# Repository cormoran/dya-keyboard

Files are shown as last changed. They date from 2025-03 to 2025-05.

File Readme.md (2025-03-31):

#  DYA Split Keyboard

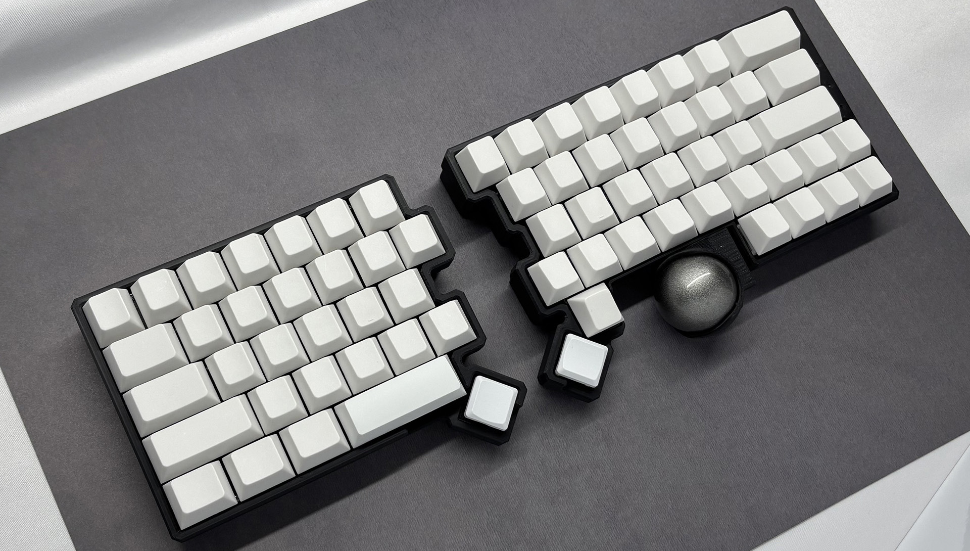
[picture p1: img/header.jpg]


## Features

- Controller: RP2040-zero (QMK) and XAIO NRF52840 plus (ZMK)
  - ZMK firmware is not available yet, since XAIO NRF52840 plus cannot be used in Japan for now.
- Layout: US and JIS
- Switch: Cherry MX compatible, hotswappable
- LED x 12 (left 4, right 4 + 4 indicator)
- PMW3610 low power trackball sensor
- Optional features by soldering additional parts
  - Lipo battery support for XAIO
  - AAA battery (1.2V NiMH or 1.5V) support

## Build Guide

[V1.0 部品取り付け済み基板（日本語）](./hardware/dya-v1/build-guide/pcba/Readme-ja.md)

## Firmware

Pre-built QMK firmware is available in latest build's artifact section in [this github actions](https://github.com/cormoran/dya-keyboard/actions/workflows/main.yml).

Three binaries (via, us, jis) are zipped in `dya_qmk_latest.zip`. `via` binary supports [VIA](https://www.usevia.app/) and [Remap](https://remap-keys.app/) to change keymapping. Keyboard definition json for VIA is available in [`./firmware/qmk/keybaords/dya/dya-via.json`](https://github.com/cormoran/dya-keyboard/blob/main/firmware/qmk/keyboards/dya/dya-via.json).

## Gallery

- Keycap: [acid-caps](https://keeb-on.com/collections/acid-caps) or no-brand white cap
- Trackball: 34mm

### US Layout setup

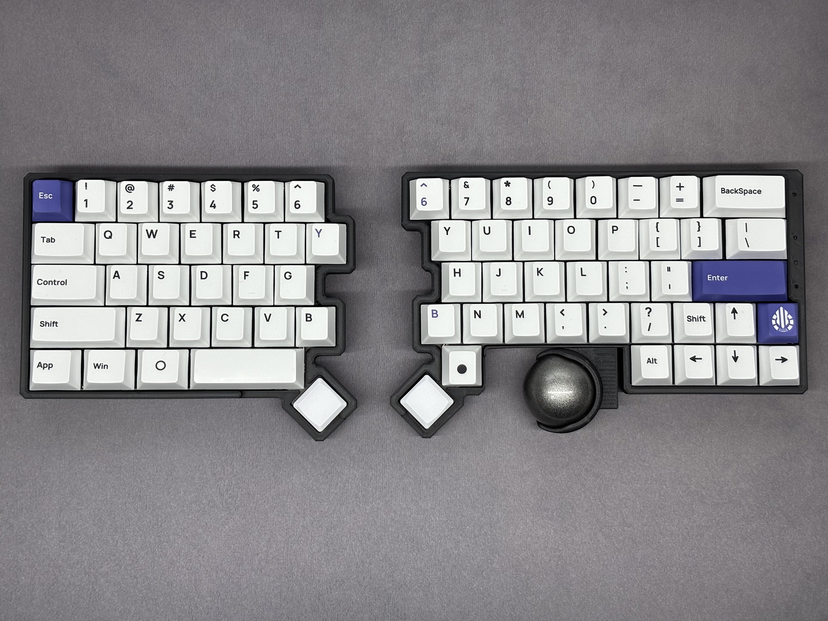
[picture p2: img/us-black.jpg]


#### LED decoration and indicators

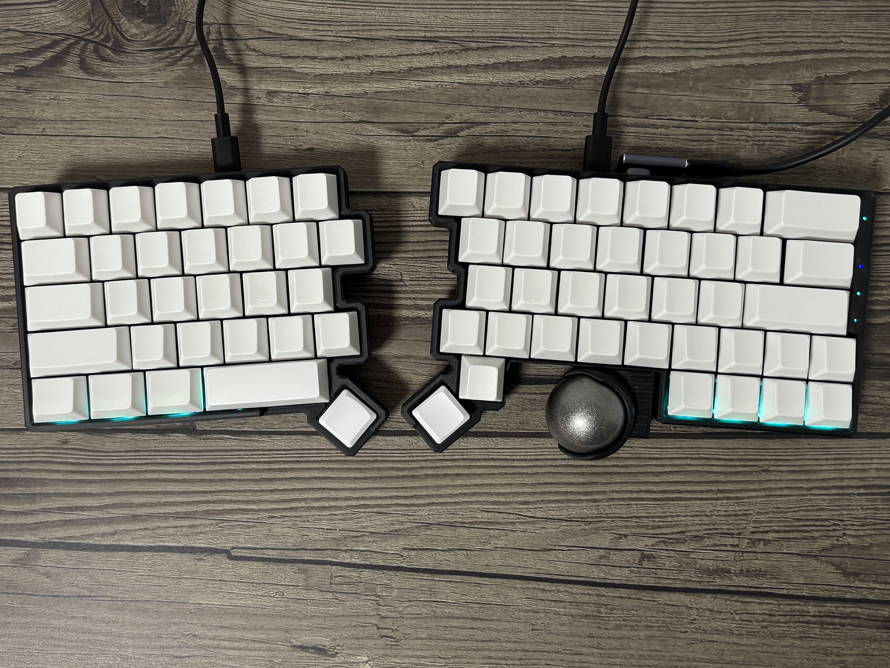
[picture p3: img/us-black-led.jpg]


### JIS Layout setup

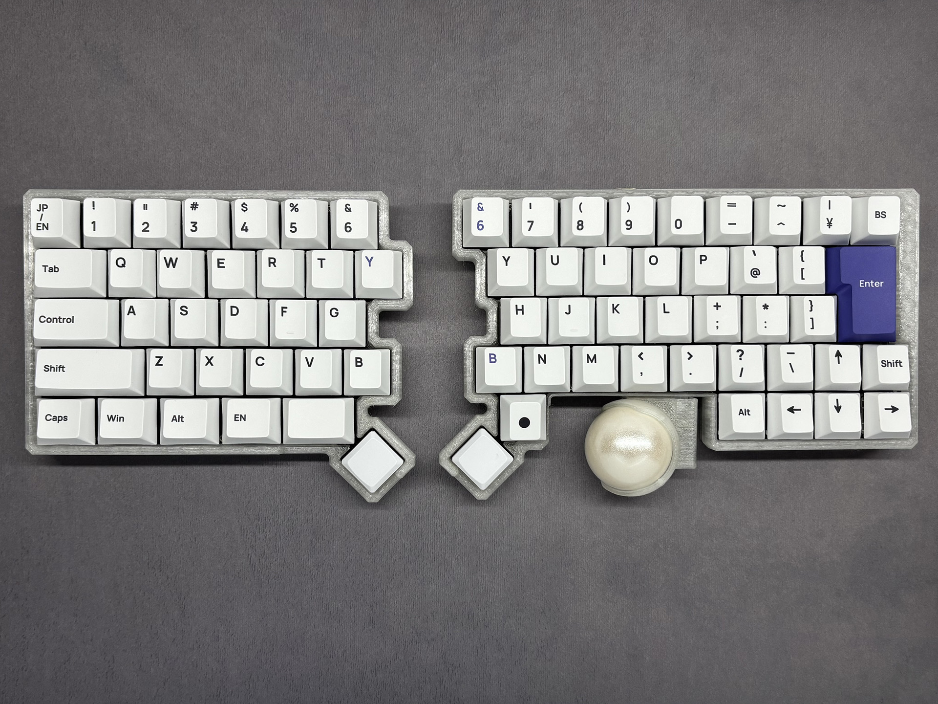
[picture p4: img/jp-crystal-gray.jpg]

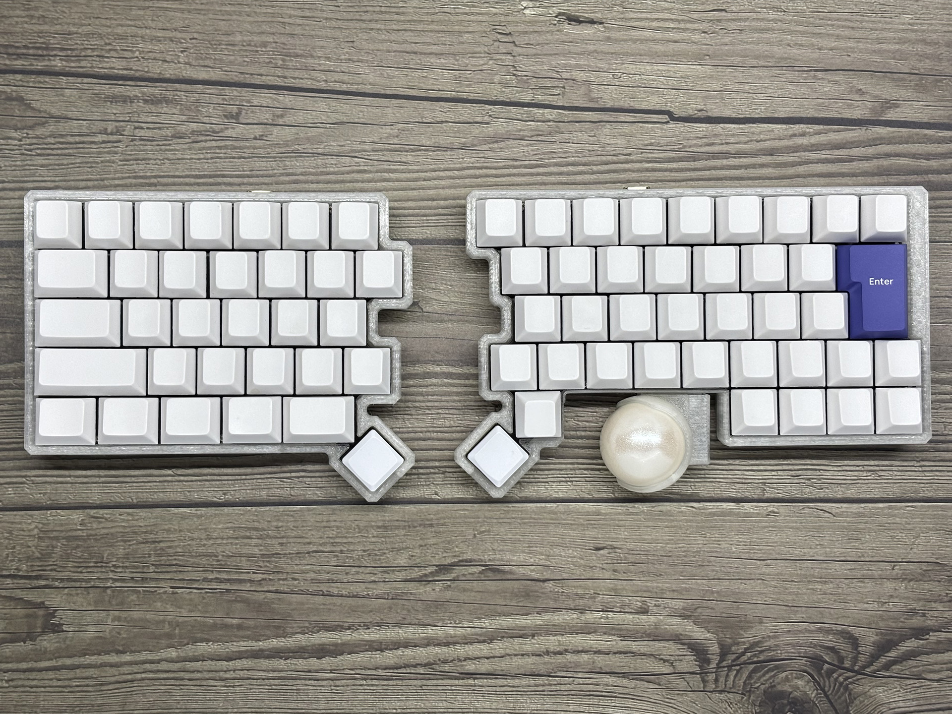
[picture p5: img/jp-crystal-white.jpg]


### Schematic

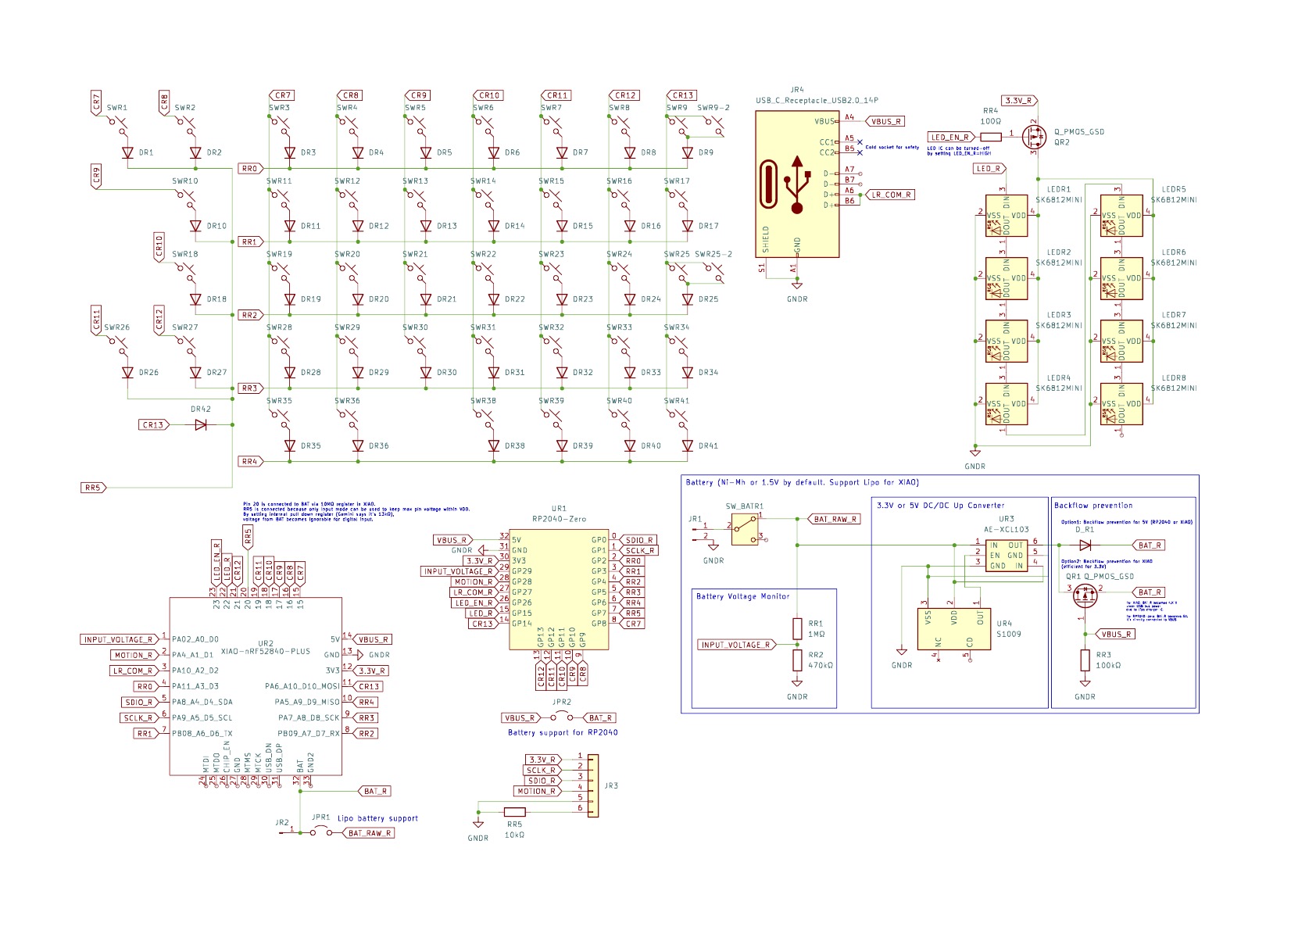
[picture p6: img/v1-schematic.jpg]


## Shop

Available in https://cormoran707.booth.pm/items/6705756

## License

- QMK firmware (./firmware/qmk_firmware/\*): Inherits its license. Majority of them are under GPLv2. See its own repository.
- DYA logo  (./img/dya.svg): All rights reserved.
- Other keyboard pictures under ./img: CC BY
- Hardware
  - kicad library (./hardware/kicad_library/\*) and sch (\*.kicad_sch): MIT
  - PCB (\*.kicad_pcb): CC BY-NC
  - Case data (\*.stl): CC BY

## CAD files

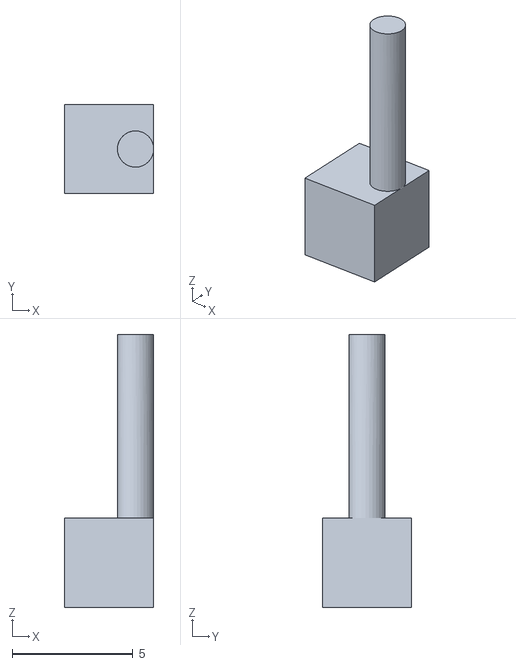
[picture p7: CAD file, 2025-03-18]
hardware/dya-v1/case/led.stl
3.70 x 3.70 x 11.3

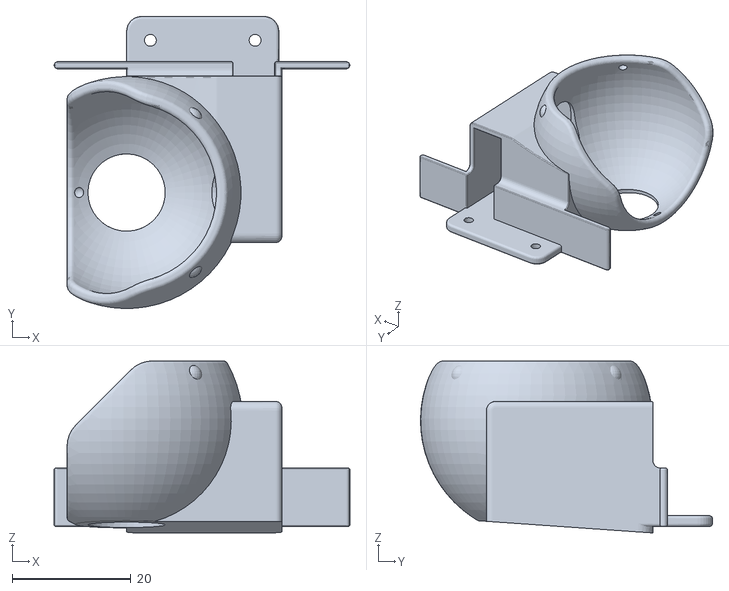
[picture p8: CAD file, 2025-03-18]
hardware/dya-v1/case/trackball-34mm.stl
49.7 x 49.1 x 28.9

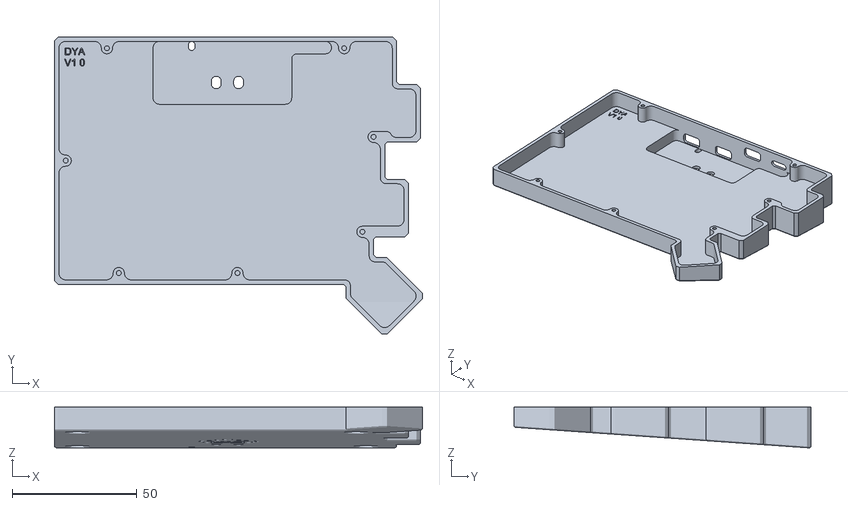
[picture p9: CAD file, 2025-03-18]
hardware/dya-v1/case/bottom-left.stl
147.7 x 119.2 x 16.4

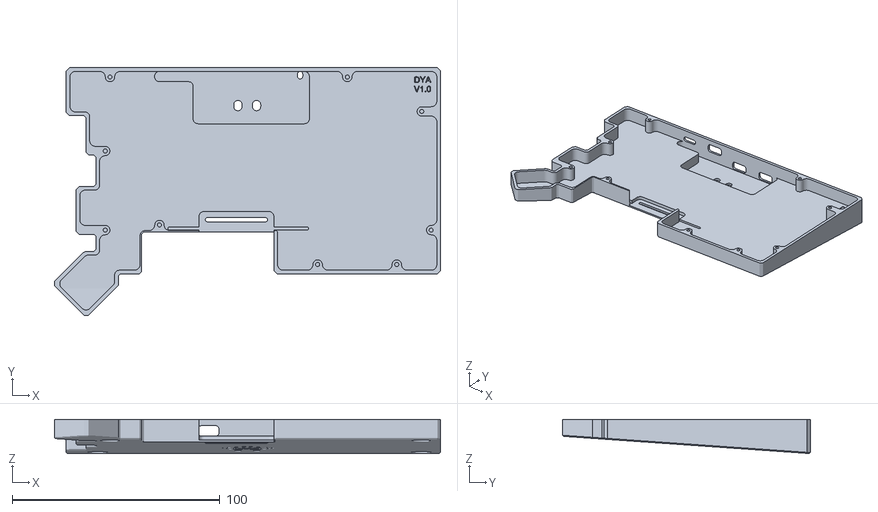
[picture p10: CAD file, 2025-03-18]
hardware/dya-v1/case/bottom-right.stl
185.9 x 119.2 x 16.4

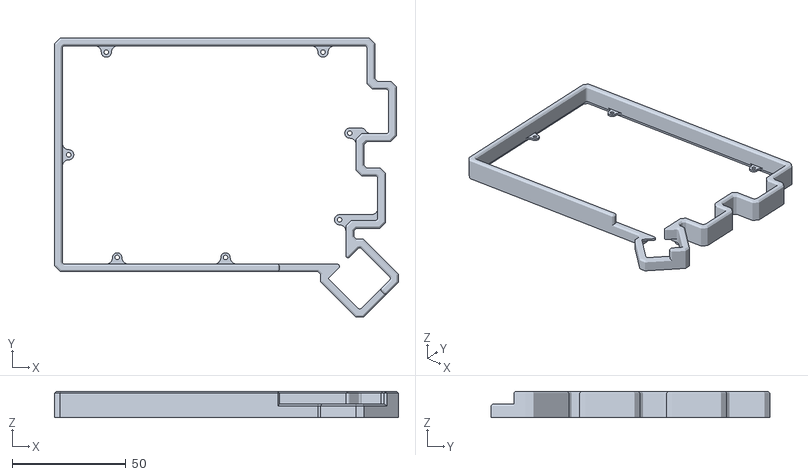
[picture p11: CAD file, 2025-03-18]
hardware/dya-v1/case/top-left.stl
151.2 x 122.7 x 11.5

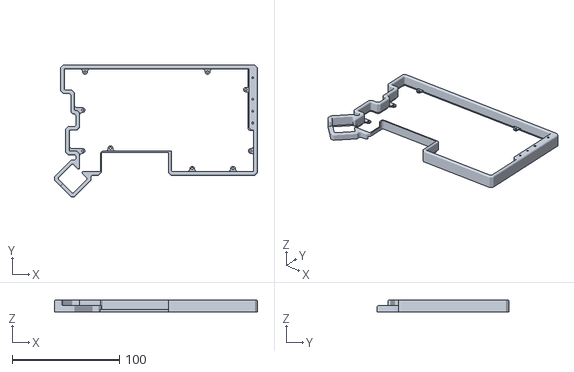
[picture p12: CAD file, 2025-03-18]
hardware/dya-v1/case/top-right.stl
189.4 x 122.7 x 11.5

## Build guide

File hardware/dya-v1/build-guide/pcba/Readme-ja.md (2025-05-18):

#  DYA v1.0 ビルドガイド

https://cormoran707.booth.pm/items/6705756 で配布中のキット向けのビルドガイドです。

## 更新履歴

| 日付 | 内容 |
| --- | --- |
| 2025/04/01 | ファームウェアのダウンロード先を変更、[ファームウェアガイド](../firmware-guide-ja.md)を追加 |

## 別途購入が必要な部品

- MX 互換キースイッチ
  - US 配列にする場合 x69
  - JIS 配列にする場合 x71
- キーキャップ
  - US, JIS 両方で必要なキーキャップがすべて揃っている [acid-caps](https://keeb-on.com/collections/acid-caps) がおすすめです
  - 以下の３点が通常の配列と異なります。下で画像付きで説明しています。
    - "6", "Y", "B" が左右２つ必要
    - US 配列では 2.75U、JIS 配列では 1.5U のスペースキー
    - R1(最下列)に４つ、R2 (一つ上の列)に１〜２つの 1U キー
- スタビライザー 2U x4 (US) or x2 (JIS)
  - なしでも動作はします
  - JIS 配列でも左親指部分を 2.75U で作ることもできます。その場合は３つ必要です。
- **34mm** トラックボール用ボール
  - 色は自由ですが、色によって反応が悪くなる場合があります
- RP2040-zero x2
- **高さ 3.5mm の**コンスルー 46pin (左右 23pin ずつ) 分
  - このガイドでは [12pin のコンスルー](https://www.switch-science.com/products/7448?variant=42382161215686)４つを分割して使用します
- USB ケーブル
  - Type C to C ケーブル（左右接続用）x1
  - Type C ケーブル（PC 接続用）x1
  - 通信用ケーブルが必要です。充電専用ケーブルでは動作しないので注意してください
- 適当なテープ
  - FFC ケーブルをケースに固定するために使います

### 必要なキーキャップサイズ

以下の例では、斜めになった親指キー部分には Tecsee Pudding Medium Linear Switch と Tai-Hao Thins low profile keycap を使用して高さを抑えています。
また、一部のスペースキーはキーキャップを上下逆にすることで親指に角が当たらないようにしています。

#### US 配列

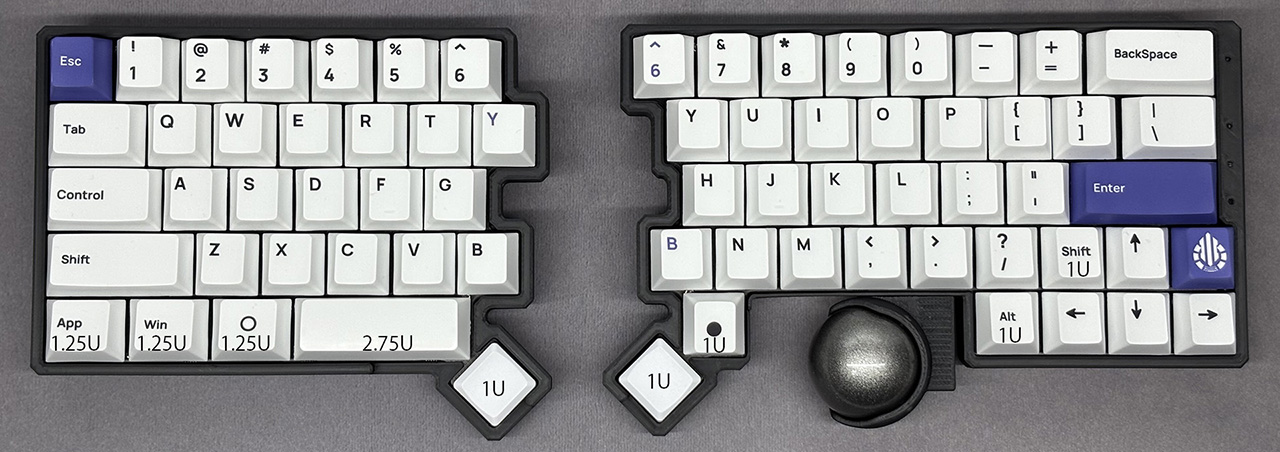
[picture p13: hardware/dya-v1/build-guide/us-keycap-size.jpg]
US


#### JIS 配列

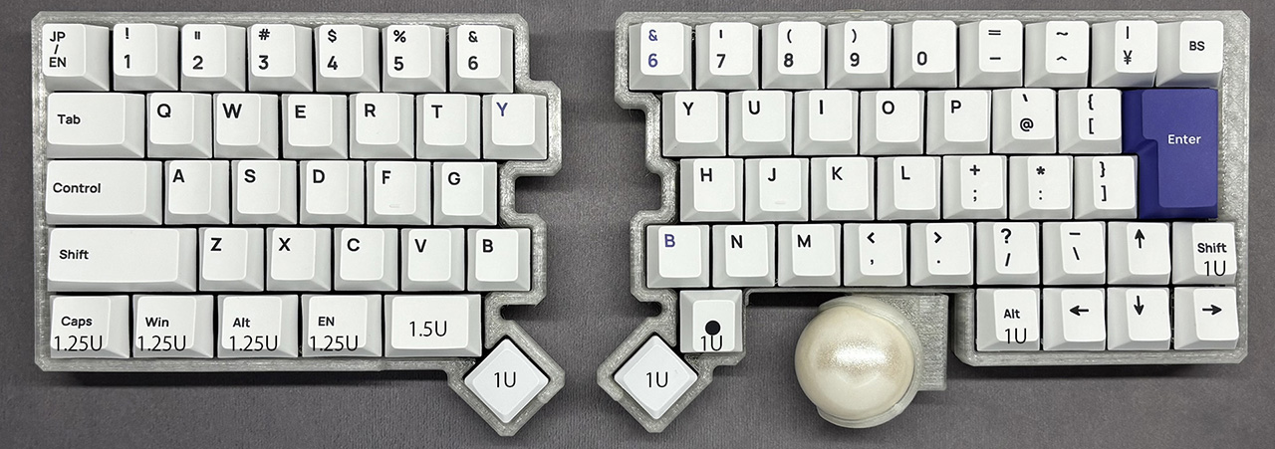
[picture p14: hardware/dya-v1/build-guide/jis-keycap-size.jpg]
JIS


## 必要な工具

- はんだ、はんだごて
  - RP2040-zero と、PMW3610 ははんだ付けが必要です
- ニッパー
- プラスドライバー（M2 ネジ用）

## キットに含まれる部品

- 回路基板(左、右、トラックボール基板が接続されたもの、厚み 1.6mm)
- トッププレート（左、右が接続されたもの、厚み 1.2mm）
- PMW3610 センサー IC とレンズ
- 3D プリント製ケース（左上下、右上下、34mm トラックボールホルダー）
- M2 ねじ 5mmx16 (ケース上下接続用)
- M2 ねじ 4mmx2 (トラックボールケース接続用)
- 6pin FFC ケーブル (トラックボール基板接続用)
- ゴム足 x8

| PCB, トッププレート  | ケースなど |
| --- | --- |
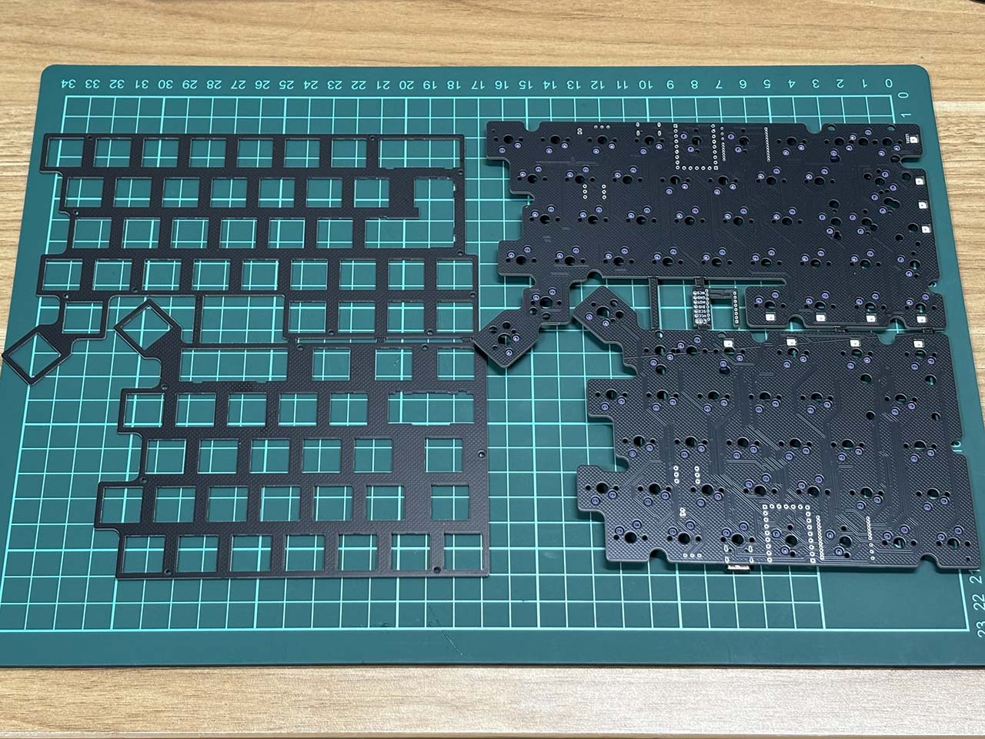
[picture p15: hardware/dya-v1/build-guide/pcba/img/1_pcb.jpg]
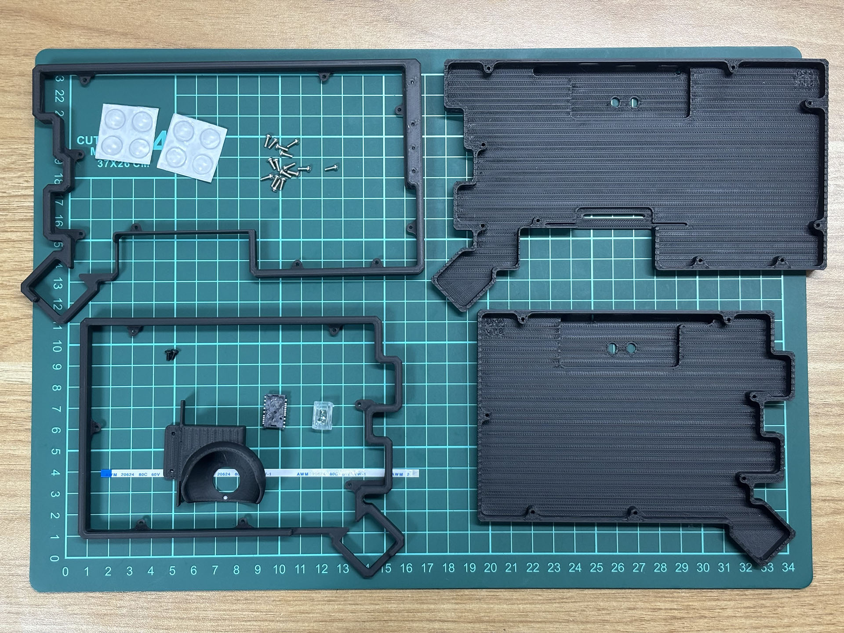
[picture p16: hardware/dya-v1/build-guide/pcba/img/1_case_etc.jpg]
|  |  |

## 注意点

- FFC ケーブルの面裏、配線に注意
- ネジを強く締めすぎない
- 使用時は RP2040-zero のコンスルーが外れてしまわないように注意

## 手順

[フォーム MOD のガイド](../form-mod-ja.md) も事前に軽く確認してから組み立てみてください。

### 1. 基板の切り離し

以下の２つの基板を切り離します



小さなドリル穴で接続されている部分をニッパーなどで切断してください。

#### 1.1 回路基板

以下のように３つの基板に分かれます。

基板どうしを接続していた切れ端は使わないので捨ててください

切り取った部分にバリが目立つ場合はニッパーやヤスリで平らにするとケースとの干渉が防げます。

配線部分を傷つけないように注意してください。

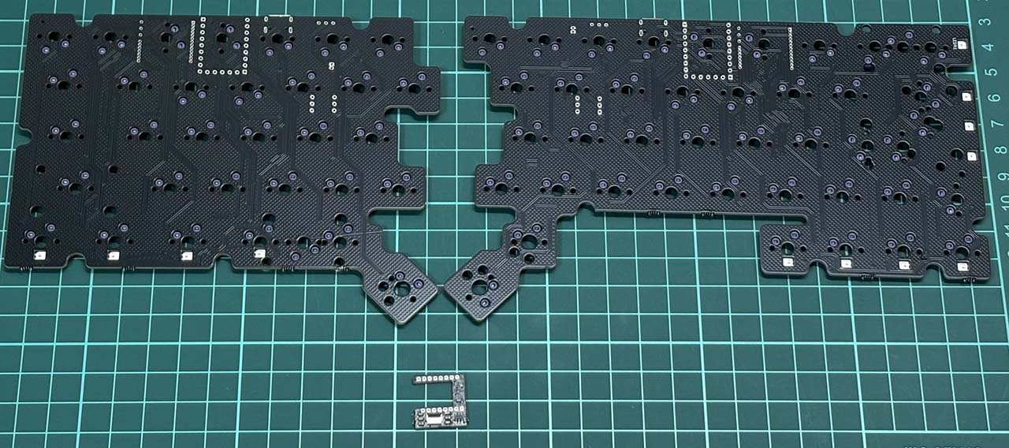
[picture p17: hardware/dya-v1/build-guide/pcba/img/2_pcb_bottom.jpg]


#### 1.2 トッププレート

トッププレートも同様に分離してください。
トッププレートは薄い部分があるので、接続部以外が破損しないように注意してください。

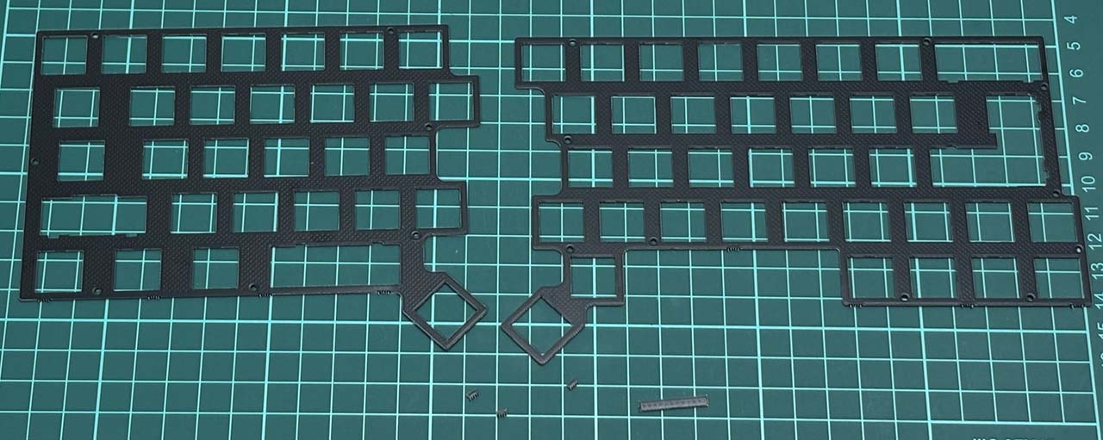
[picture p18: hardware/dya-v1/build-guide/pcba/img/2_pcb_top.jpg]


### 2. はんだ付け

#### 2.1 PMW3610

キット同梱の以下の３つのパーツを用意してください

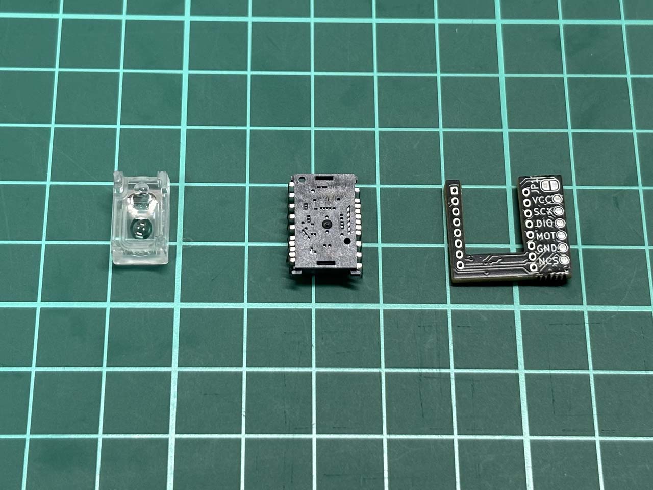
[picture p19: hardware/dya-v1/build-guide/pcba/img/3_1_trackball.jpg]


IC を以下のような方向で基板にはんだ付けします。
IC が基板に対して平行になるようにしてください。半田付け前にレンズがセットできるか確認することをお勧めします。
レンズは熱で溶けるので、**半田付けはレンズを外した状態で**行ってください。

| | | |
| --- | --- | --- |
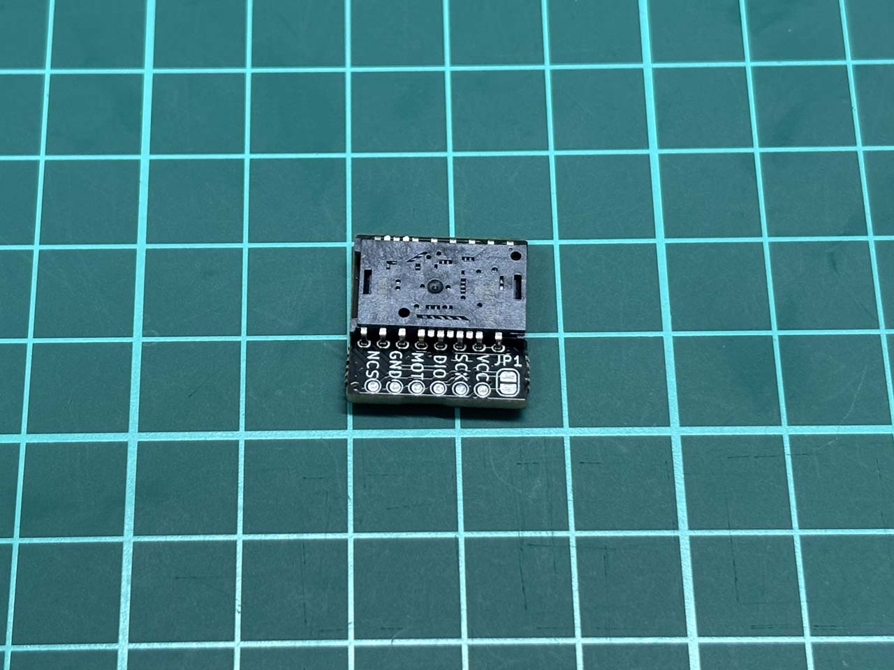
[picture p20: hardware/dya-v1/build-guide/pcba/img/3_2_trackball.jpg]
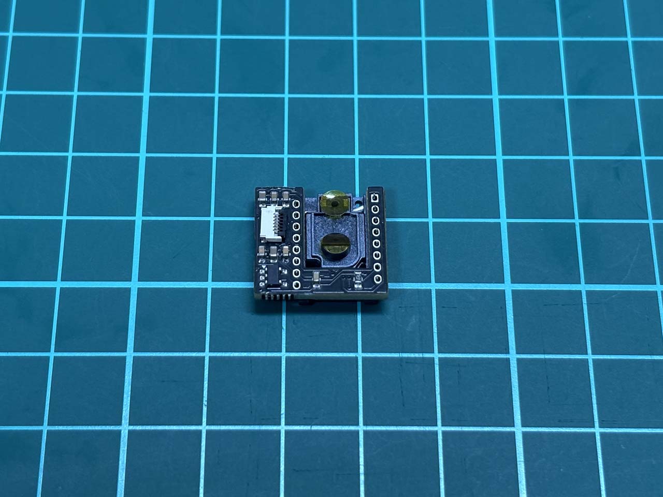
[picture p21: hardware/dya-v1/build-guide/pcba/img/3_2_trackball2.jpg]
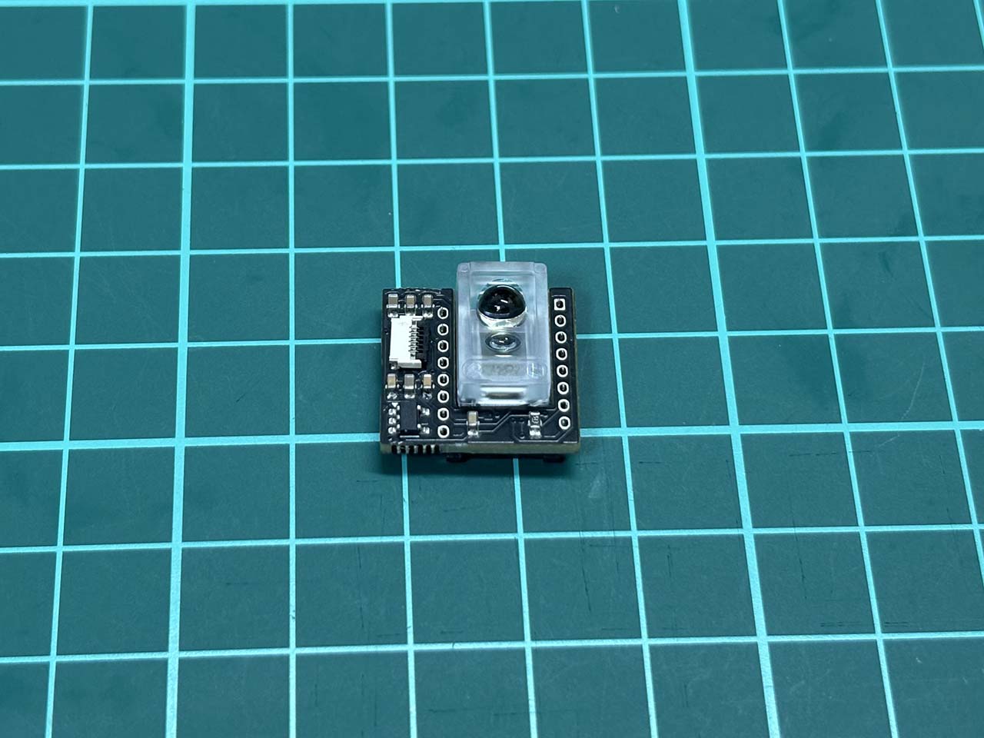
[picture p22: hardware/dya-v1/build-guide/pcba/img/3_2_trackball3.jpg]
|  |  |  |

以下のように端のピンをまずはんだ付けすると IC が固定されて作業しやすくなります。

長時間はんだごてを当てると IC が破損する可能性があるので注意してください。

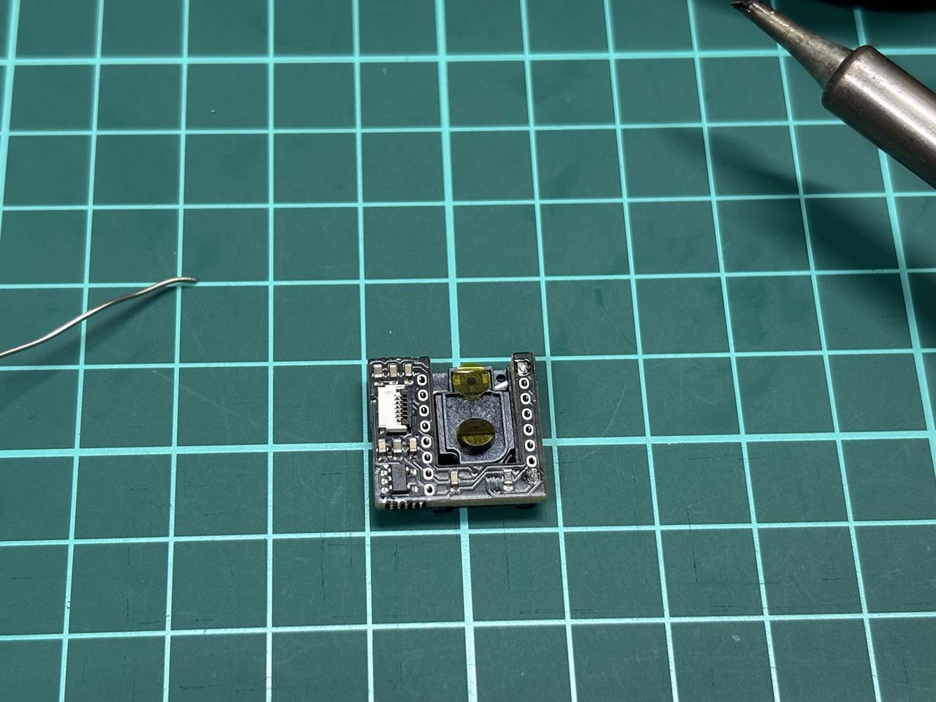
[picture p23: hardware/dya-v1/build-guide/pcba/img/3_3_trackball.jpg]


IC を取り付けたら、IC についていた透明な保護フィルムを剥がしてレンズをセットします

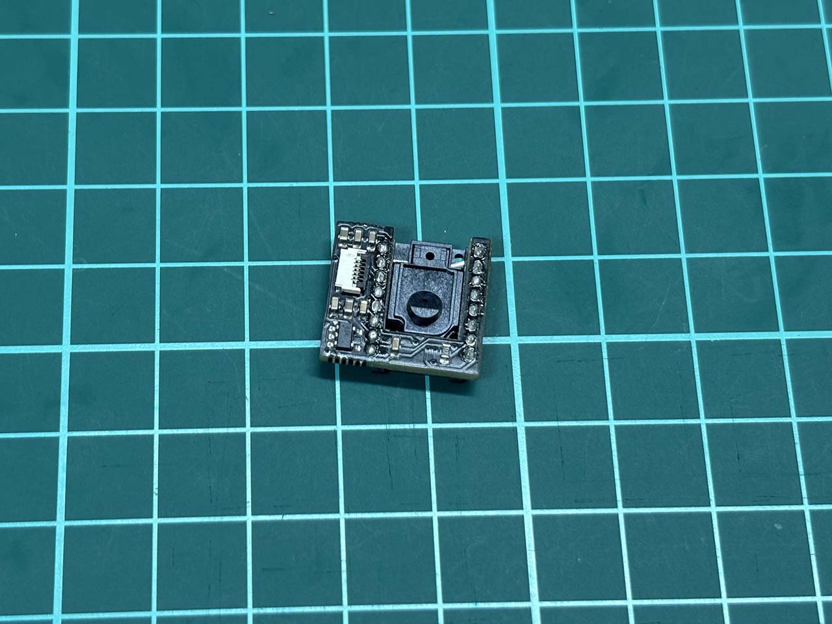
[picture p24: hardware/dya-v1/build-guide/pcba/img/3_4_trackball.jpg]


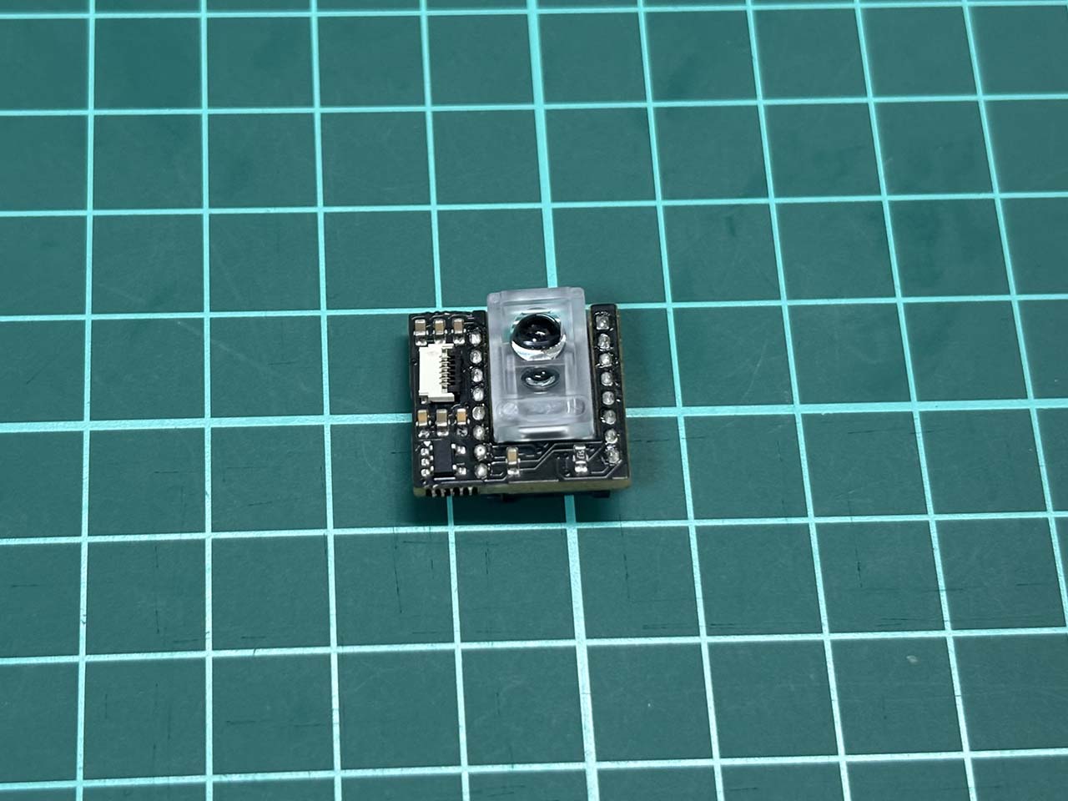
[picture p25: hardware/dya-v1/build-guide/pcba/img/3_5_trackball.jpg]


最後に IC の表側に出っ張っているレンズの足を処理します。

このままではケースと干渉するので、出っ張りをニッパーで切断するか、ハンダゴテで熱を加えて潰すように溶かしてください。
レンズが外れないように溶かすのが推奨されている方法のようですが、作者はニッパーで切断しています。

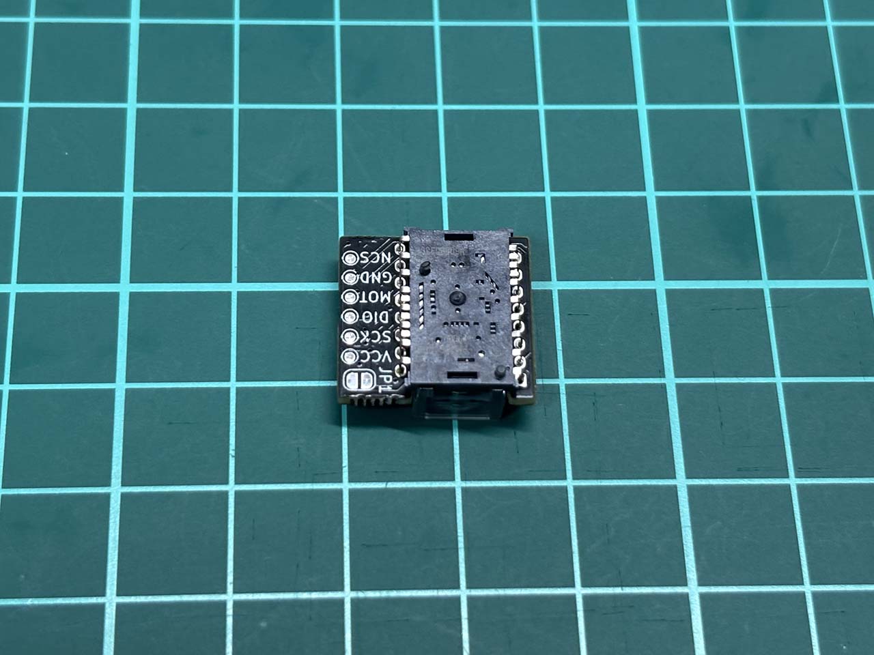
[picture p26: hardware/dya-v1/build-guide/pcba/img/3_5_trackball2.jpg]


#### 2.2 RP2040-zero

別途購入した RP2040-zero にコンスルーを取り付けます。以下の手順で２つの RP2040-zero を作ってください。まず一つ作ってファームウェアの書き込みとキーボードの動作確認までしてから、２つ目を作ると良いかもしれません。

1. 12pin コンスルー x2 を切断して 9pin x2, 3 pin x1, 2pin x1 を作ります。残った 1pin は使用しません。
2. 以下の画像のように RP2040-zero にとりつけて、**RP2040 側のみを**半田付けします。コンスルーには上下左右があるのでネットで検索して正しい方向で取り付けてください（例えば[この記事など](https://zenn.dev/digitarhythm/articles/276cd44a36ed32)）。以下の写真では左右が間違ってそうです...

| | | | |
| --- | --- | --- | --- |
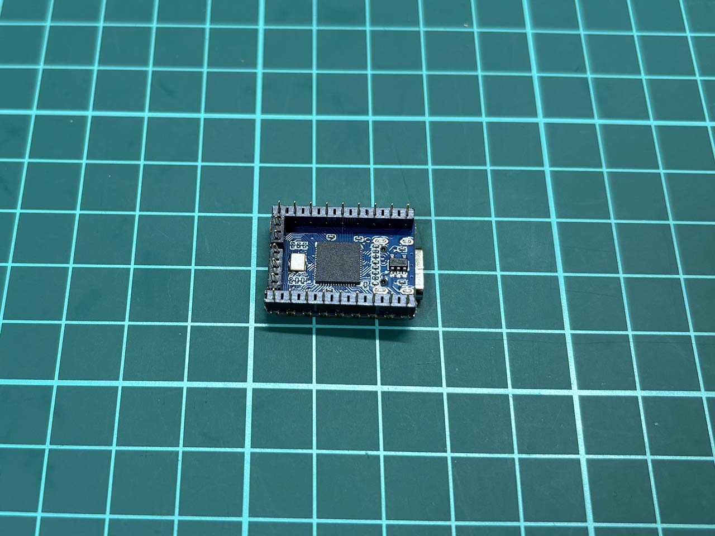
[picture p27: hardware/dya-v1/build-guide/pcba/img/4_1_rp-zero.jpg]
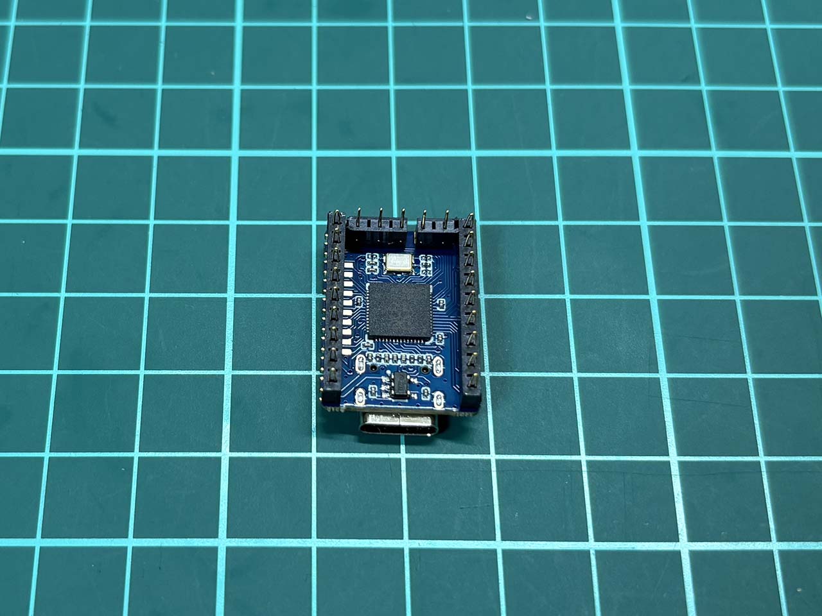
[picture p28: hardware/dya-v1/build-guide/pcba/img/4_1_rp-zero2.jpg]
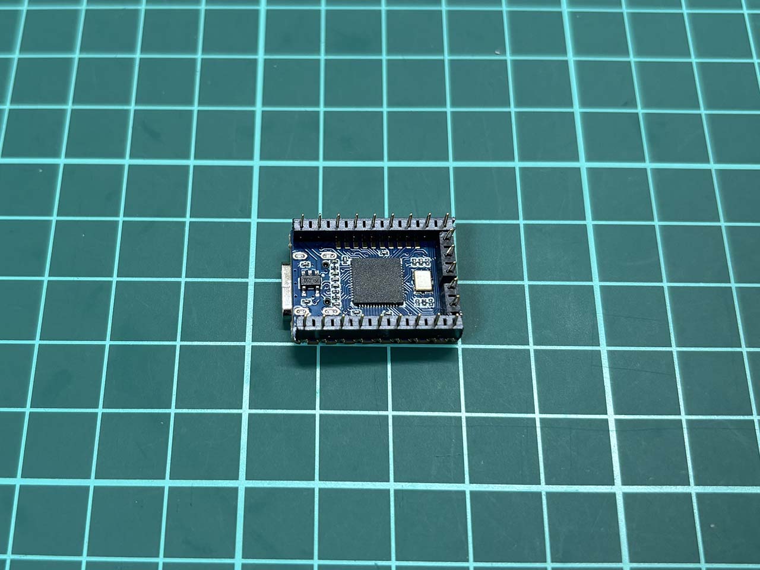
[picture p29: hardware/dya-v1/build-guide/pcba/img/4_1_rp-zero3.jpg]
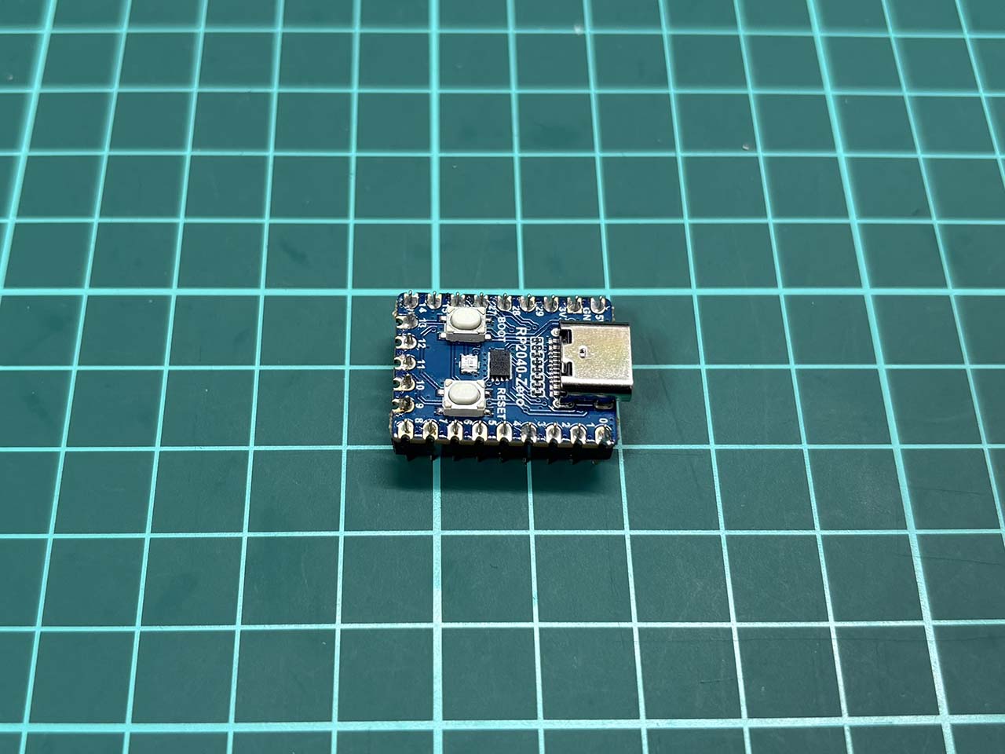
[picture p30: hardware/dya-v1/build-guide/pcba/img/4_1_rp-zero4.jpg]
|  |  |  |  |

### 3. ファームウェアの書き込み

RP2040-zero に QMK ファームウェアを書き込みます。

[ファームウェアガイド](../firmware-guide-ja.md) で画像付きで詳細なステップを解説しています。

1. [こちらのページ](https://github.com/cormoran/dya-keyboard/releases) で最新版のファームウェア（zip ファイル）をダウンロードして解凍します。
2. PR2040-zero を PC に接続します
3. Boot スイッチと Reset スイッチを同時に押して、Reset スイッチ → Boot スイッチの順で離します。PRI-PR2 という名前で USB メモリのようにデバイスが PC と接続されます。
4. 1 で解答したディレクトリに含まれるファームウェアファイルを USB メモリに移動させる要領で PRI-PR2 にコピーします。

- `via.uf2` は VIA/Remap 対応のファームウェアです。デフォルトは US 配列ですが、[VIA](https://www.usevia.app/) or [Remap](https://remap-keys.app/) でノーコードでキー配列を変更できます。
  VIA, Remap で必要な json ファイルは [/firmware/qmk/keybaords/dya/dyya-via.json](https://github.com/cormoran/dya-keyboard/blob/main/firmware/qmk/keyboards/dya/dya-via.json) に置いています。
- `dya_us.uf2`, `dya_jis.uf2` は VIA 未対応の US, JIS 配列ファームウェアです。

### 4. 動作確認と組み立て

右側のキーボードから組み立てます。

1.  回路基板にコンスルーを取り付けた RP2040-zero を差し込みます。抜き差しの際に斜めになるとコンスルーが曲がるので注意して上からまっすぐ抜き差ししてください。

2.  RP2040-zero の USB ポートを PC と接続します。接続が問題なければキーボード側基板に搭載した LED が点灯します。点灯しない場合は PC が RP2040-zero を認識しているか、コンスルーの接続に不良がないかを確かめてください。動作確認ができたら RP2040-zero から USB ケーブルを取り外してください。

| | |
| --- | --- |
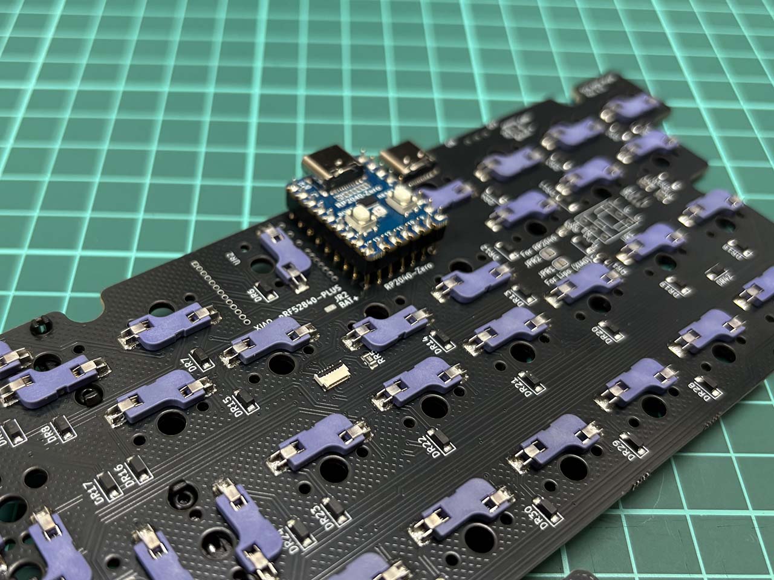
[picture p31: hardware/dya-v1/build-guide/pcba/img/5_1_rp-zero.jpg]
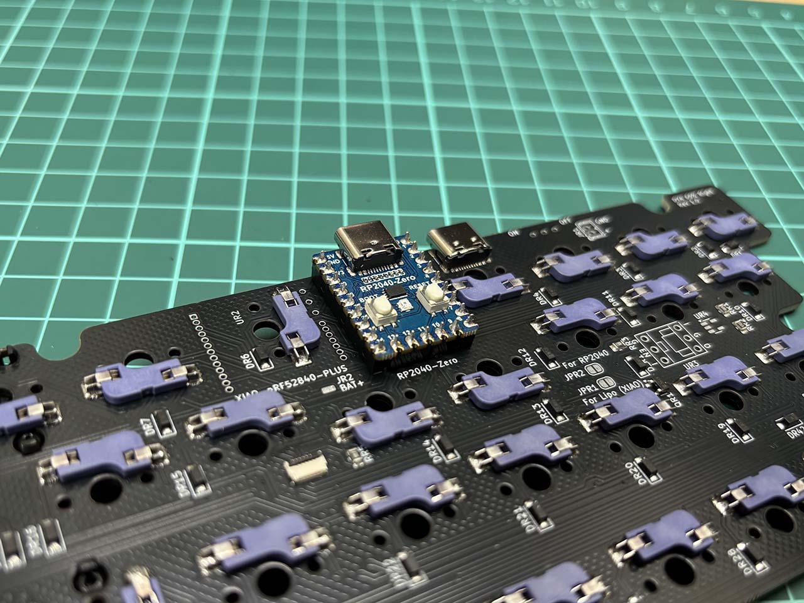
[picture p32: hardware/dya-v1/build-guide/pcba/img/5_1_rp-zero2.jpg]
|  |  |

3. スタビライザーの取り付け

基板にスタビライザーを取り付けます。

US 配列の場合は以下のように２箇所、JIS 配列の場合は enter key 用に１箇所取り付けてください。
スタビライザーにルブをする場合はこのタイミングか、 6 のケース組み立て前のタイミングでしてください。

| | |
| --- | --- |
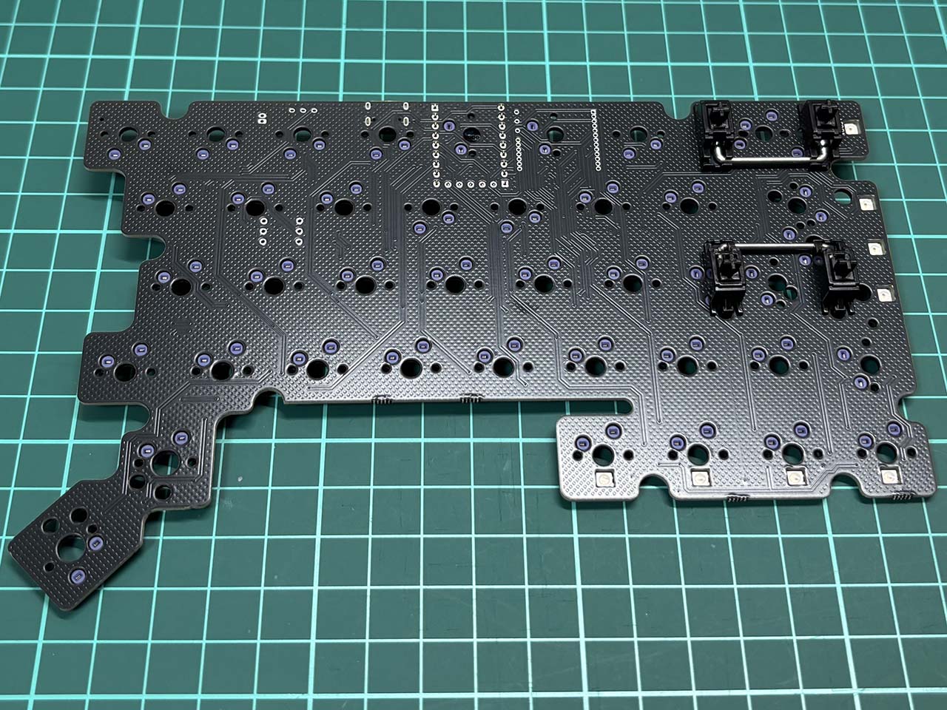
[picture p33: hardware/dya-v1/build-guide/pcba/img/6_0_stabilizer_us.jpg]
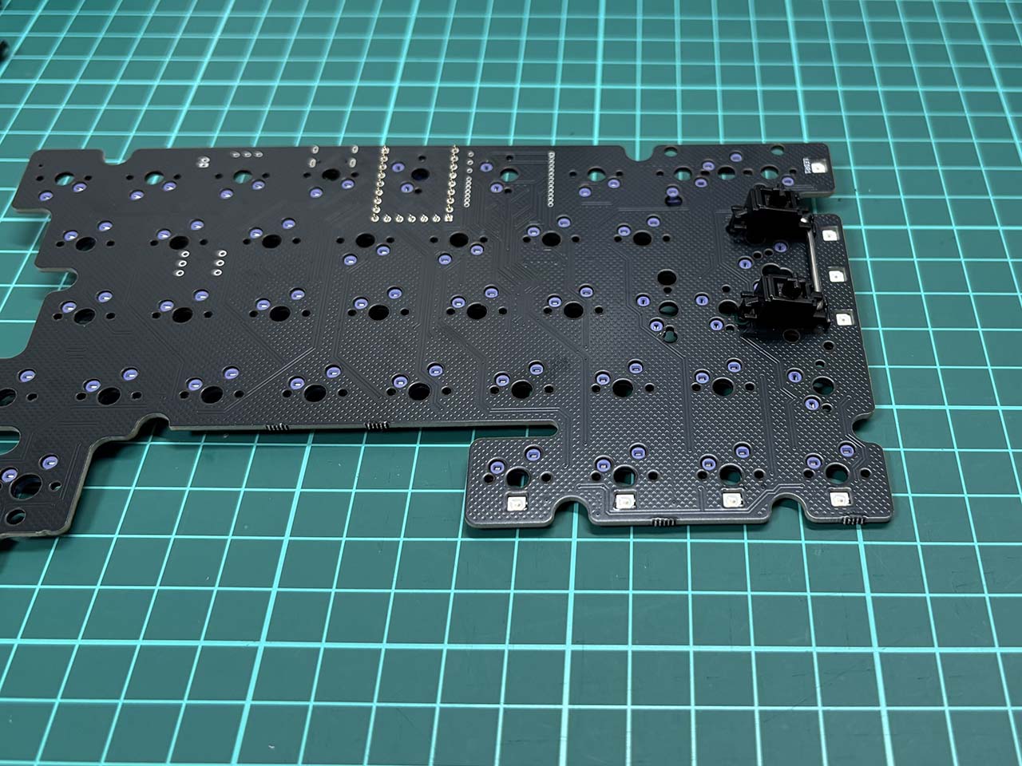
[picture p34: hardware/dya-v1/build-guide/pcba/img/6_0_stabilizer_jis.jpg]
|  |  |

4. トラックボール基板を FFC ケーブルで接続します。

FFC ケーブルは乱雑に扱うと断線します。丁寧に扱ってください。

- まずキーボード基板（右）に FFC ケーブルを接続します。
- 写真のソケットの黒い部分を垂直に立ててロックを解除します
- FFC ケーブルの青い部分が表側に来るように差し込んで、黒い部分を倒してロックケーブルをロックします
- 同様にトラックボール基板に FFC ケーブルを接続してください。FFC ケーブルの面裏に注意してください。

- トラックボール基板をトラックボールケースに差し込みます。奥まで差し込んでください。
- トラックボールケースをボトムケース（右）に写真のようにはめ込みます。
- FFC ケーブルをいい感じに配線しつつキーボード基板をケースにはめ込みます。
  - この時に FFC ケーブルをテープでボトムケースに固定してください。
  - FFC ケーブルは軽く折り目をつけて曲げて、キーボード基板を押し込んだ際に FFC ケーブルが縦に潰されないように配線してください。
  - トラックボールケースの位置調整ができるように、FFC はトラックボール側に十分なゆとりを持たせるように固定してください。ケーブルが張った状態だと位置調整時や使用中にケーブルが外れる可能性があります。

基板取り付け時に PR2040-zero とボトムケースの間に適当な詰め物をしておくと良いかもしれません。
作者は静音性向上によく使われるポロンシート(5mm)を詰めることで使用中にコンスルーが外れる可能性を軽減しています。

| | | | | | |
| --- | --- | --- | --- | --- | --- |
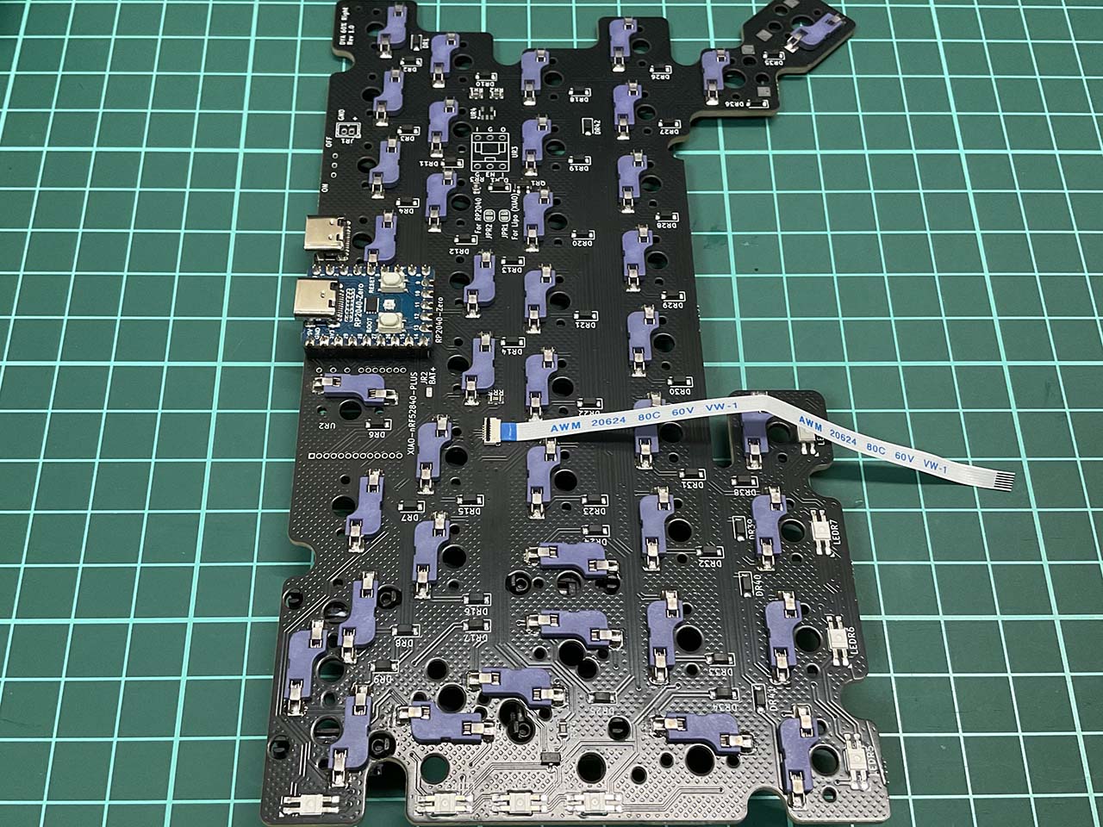
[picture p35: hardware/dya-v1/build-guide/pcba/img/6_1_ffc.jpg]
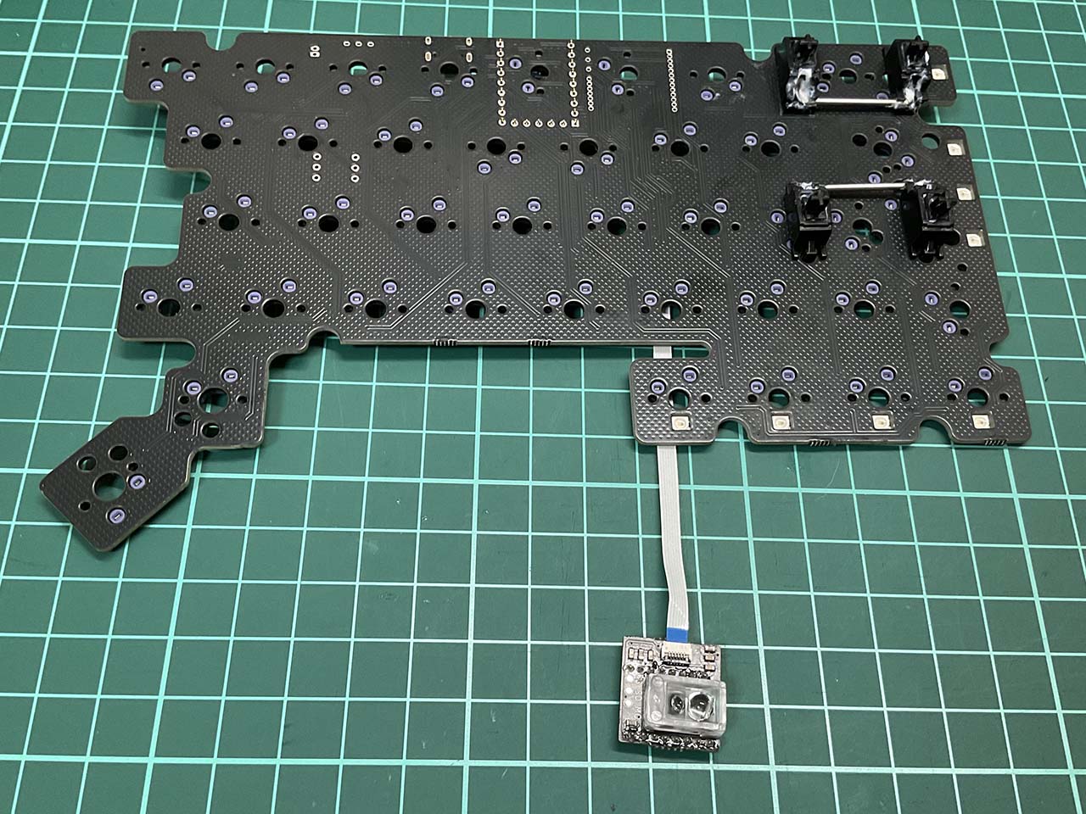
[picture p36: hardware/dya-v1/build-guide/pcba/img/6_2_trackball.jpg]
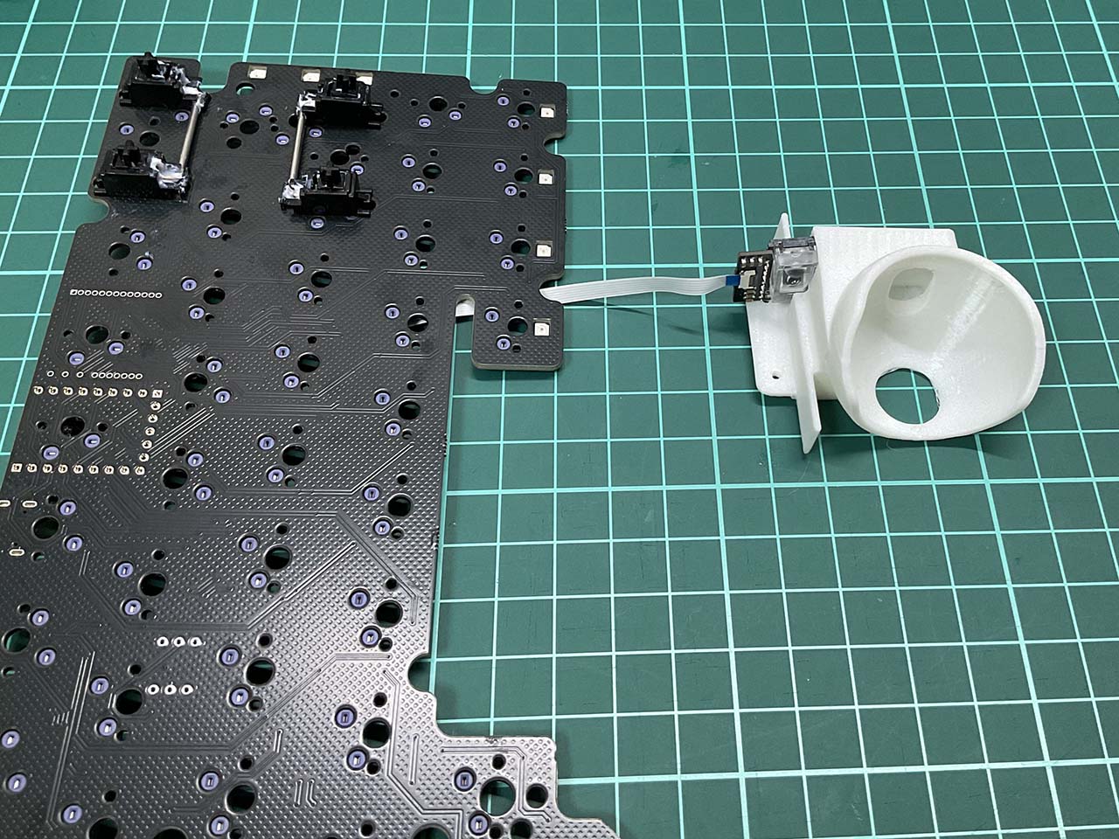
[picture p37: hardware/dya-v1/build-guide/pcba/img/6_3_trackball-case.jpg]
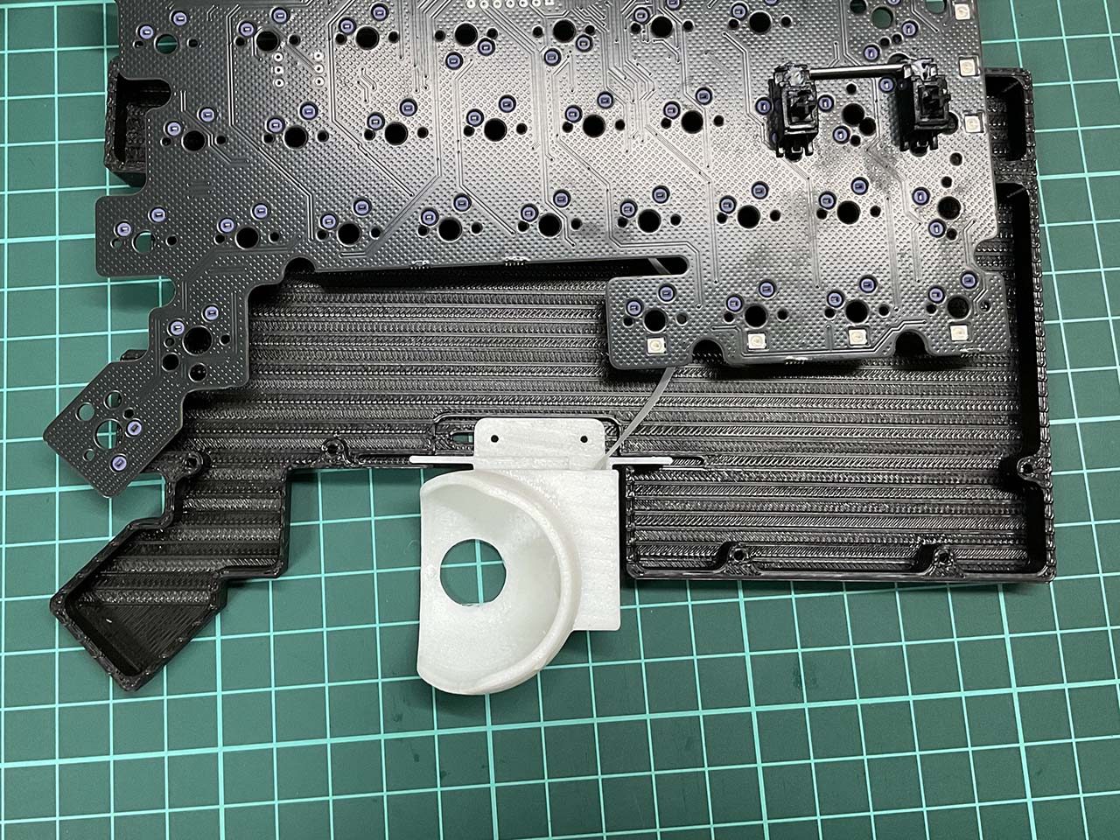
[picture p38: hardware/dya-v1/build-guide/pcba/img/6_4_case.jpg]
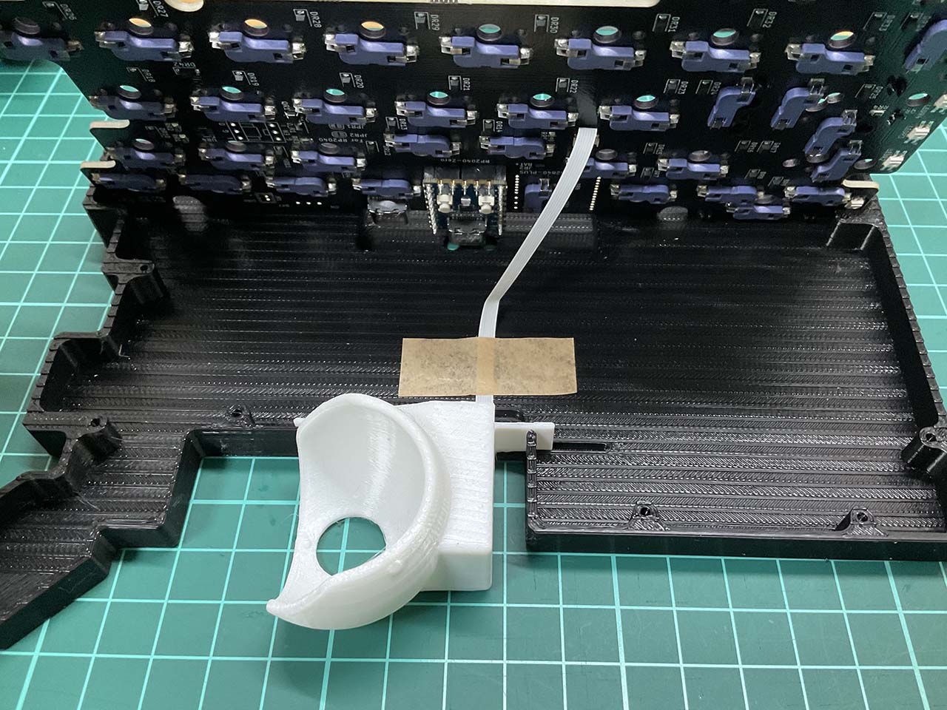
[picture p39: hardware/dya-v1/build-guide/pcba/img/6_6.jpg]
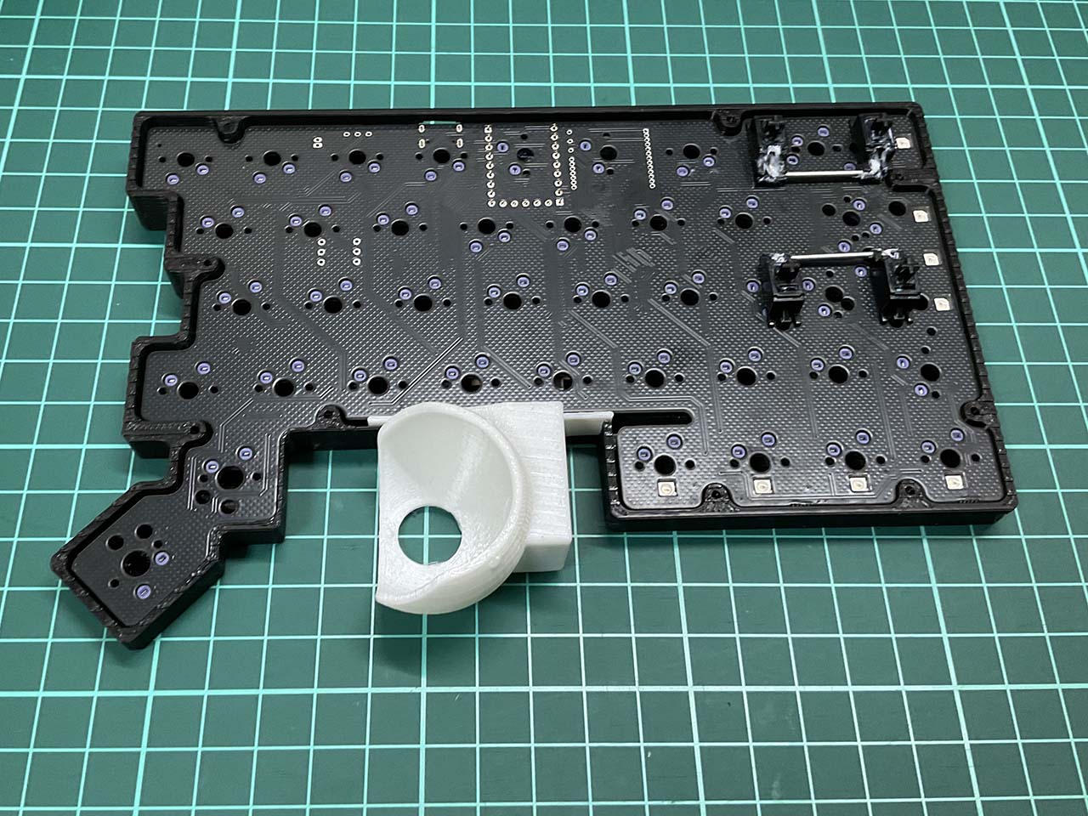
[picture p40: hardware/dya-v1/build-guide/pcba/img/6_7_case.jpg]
|  |  |  |  |  |  |

5.  トラックボールの動作確認をします。

- RP2040-zero の USB ポートを PC と接続してください。
- トラックボールケースに 34mm トラックボールをセットして、PC のポインターが動作するか確認してください。

6. トッププレートを組み立てます

- トッププレートとトップケースを用意してください。
- 以下の写真のように、親指部分でトッププレートをケースの下に差し込みながら、ケースの上からトッププレートを差し込みます。
- トップケースをボトムケースにはめ込みます

| | | |
| --- | --- | --- |
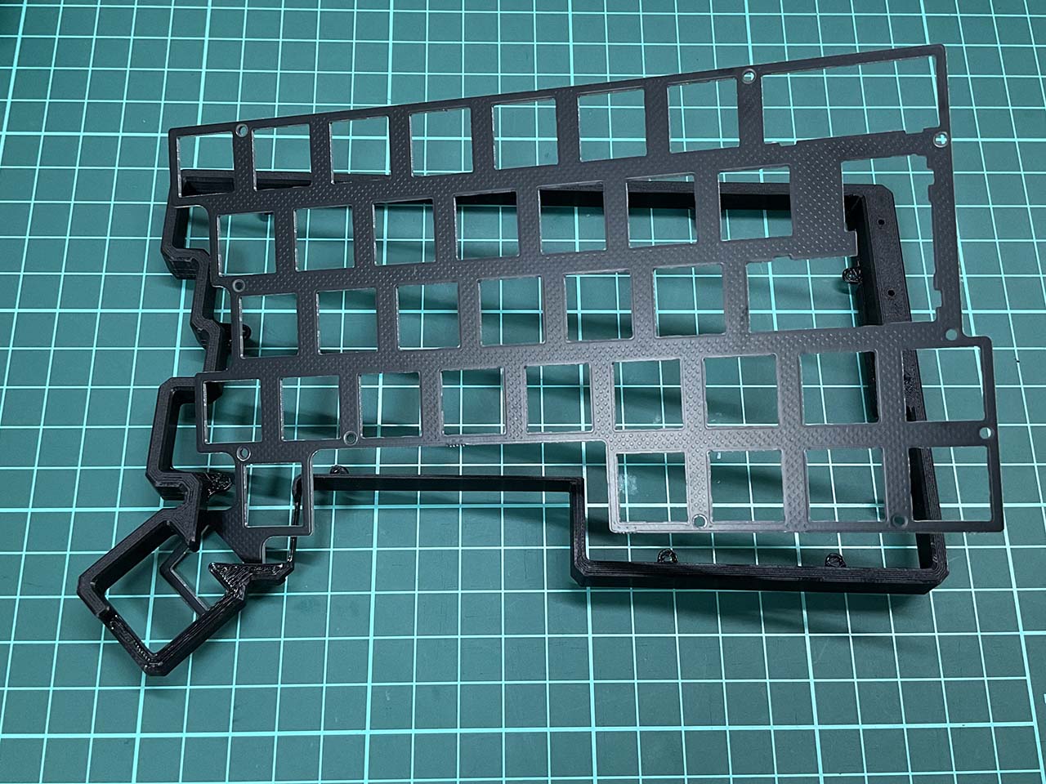
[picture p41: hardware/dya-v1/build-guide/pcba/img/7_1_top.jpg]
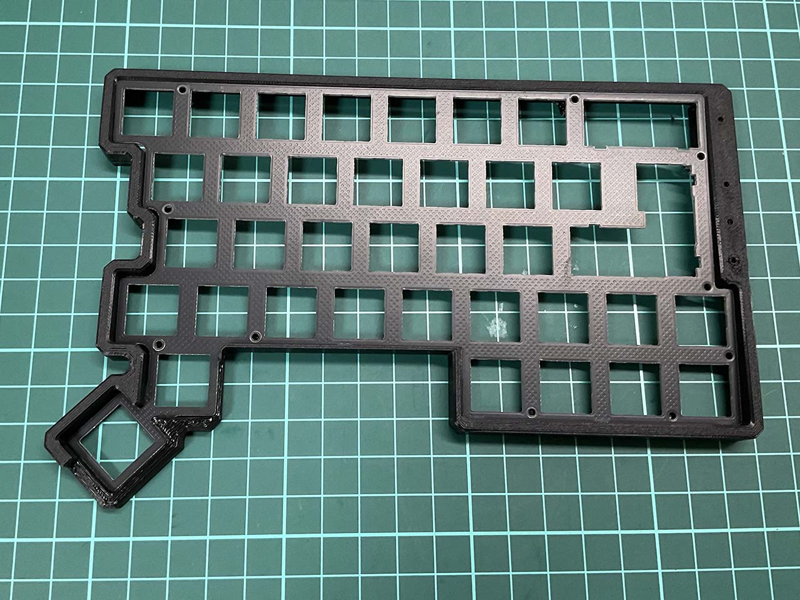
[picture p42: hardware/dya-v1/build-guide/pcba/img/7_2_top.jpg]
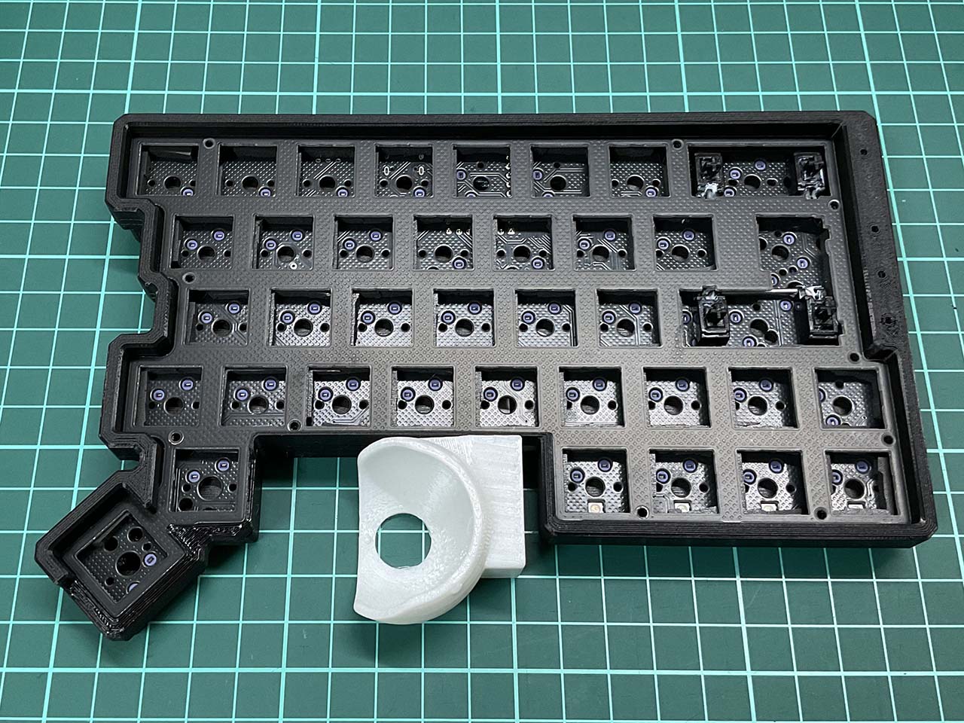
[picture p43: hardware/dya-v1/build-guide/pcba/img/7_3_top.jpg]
|  |  |  |

7. スイッチの取り付け

**スイッチの形状によって RP2040-zero のコンスルーに干渉する場合があります。干渉する場合はスイッチの干渉する部分をニッパー等で切り取ってください。** LED 部分に大きめの穴が空いたスイッチは干渉しないようです。

- スイッチのピンと基板の穴の方向に注意していくつかスイッチを取り付けます
  - スイッチの種類によっては取り付けに少し力が必要なことがあります
  - スイッチのピンが曲がっている場合、基板のソケットが破損したりスイッチが破損したりする場合があるので注意しながら差し込んでください。取り付けづらい場合は一度回路基板を取り外して裏側から支えながらスイッチをセットすると安全です。
- いくつかつけたらもう一度動作確認をします。ケースの外側の USB ソケットと PC を接続して、スイッチを押してみてください。PC 側で反応があれば動作確認成功です。
- 全てのスイッチを取り付けます

| | | |
| --- | --- | --- |
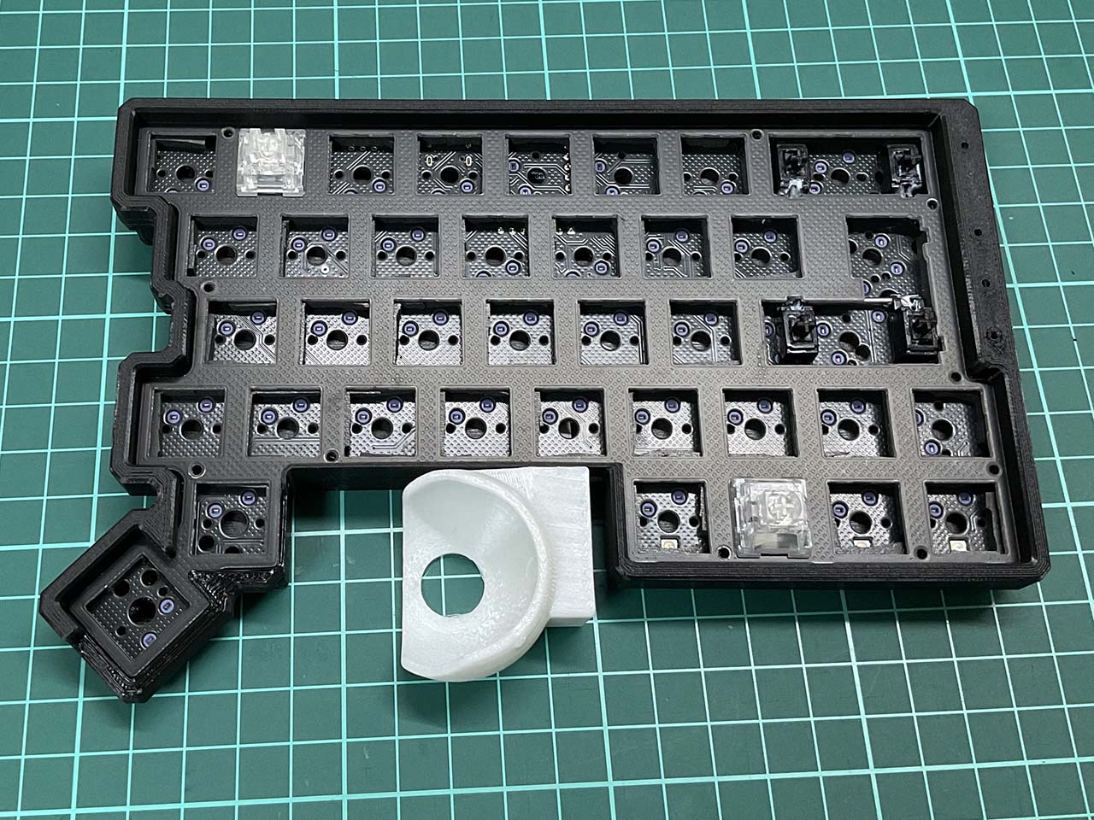
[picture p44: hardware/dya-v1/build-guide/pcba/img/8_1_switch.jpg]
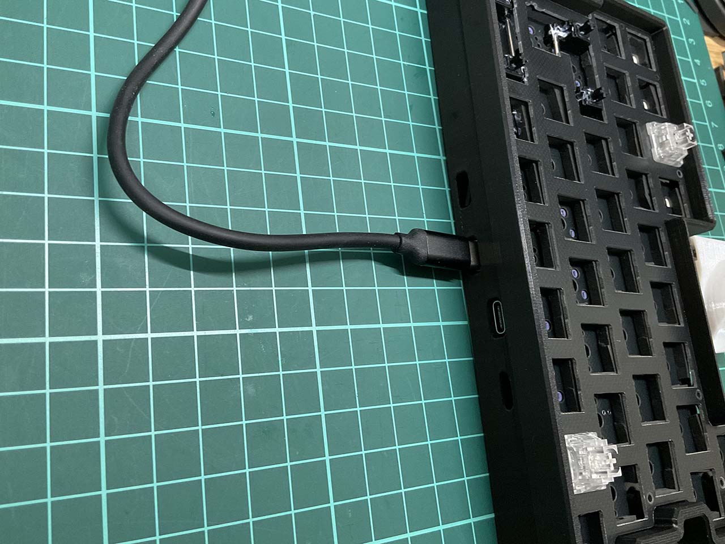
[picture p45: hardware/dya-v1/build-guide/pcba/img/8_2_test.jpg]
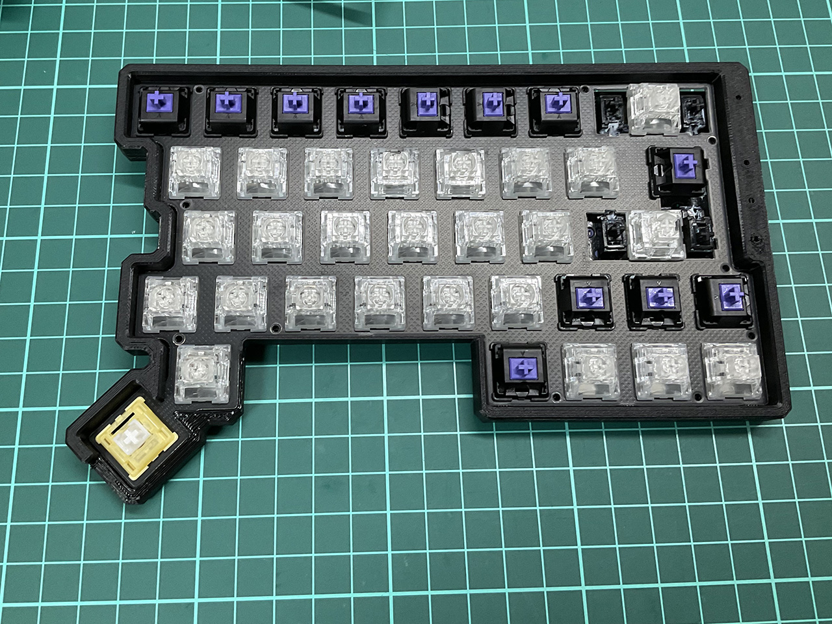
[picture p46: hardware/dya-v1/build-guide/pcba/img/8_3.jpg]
|  |  |  |

8. ねじ止め

パーツをねじ止めします。**ねじを強く締めすぎないように注意してください。** 3DP プリンタ製のパーツは強度が不十分なため簡単にネジ穴が潰れてしまいます。

- まずトラックボールケースを固定します。裏側から見ると２箇所ネジ穴があるので短いネジで止めてください。
- 次にトッププレートとボトムプレートを固定します。１０個ネジ穴がありますが、以下で示している４つを止めるだけで十分です。他の部分はお好みに合わせて固定してください。

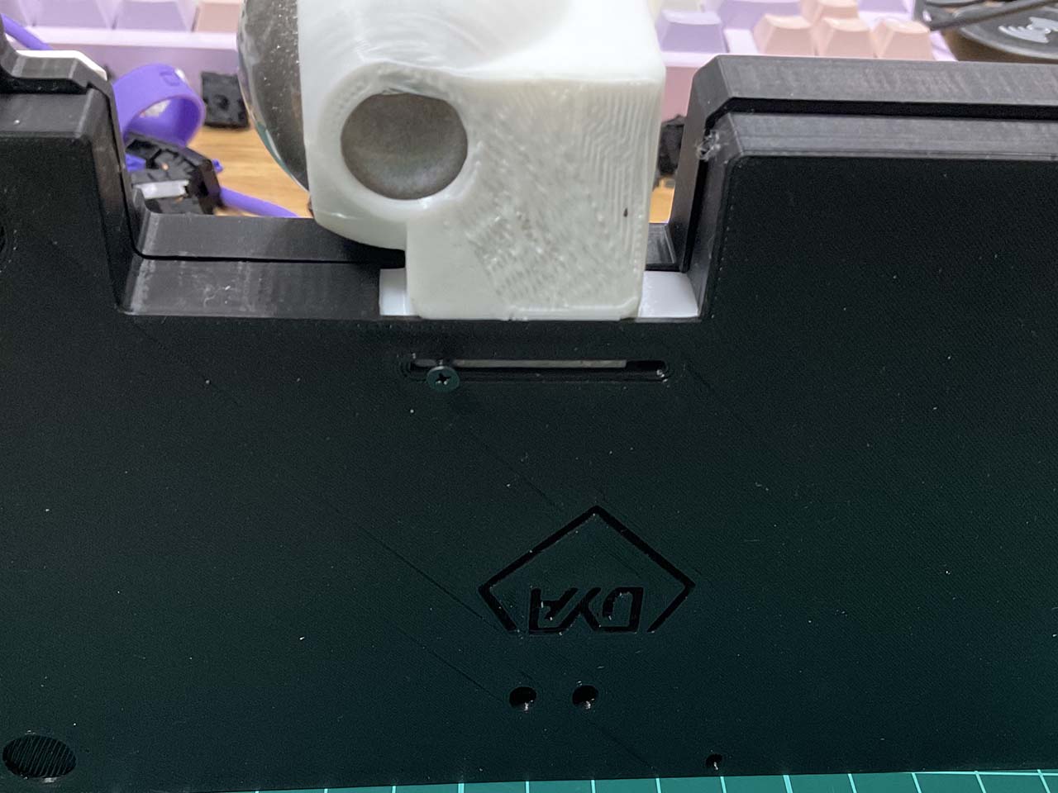
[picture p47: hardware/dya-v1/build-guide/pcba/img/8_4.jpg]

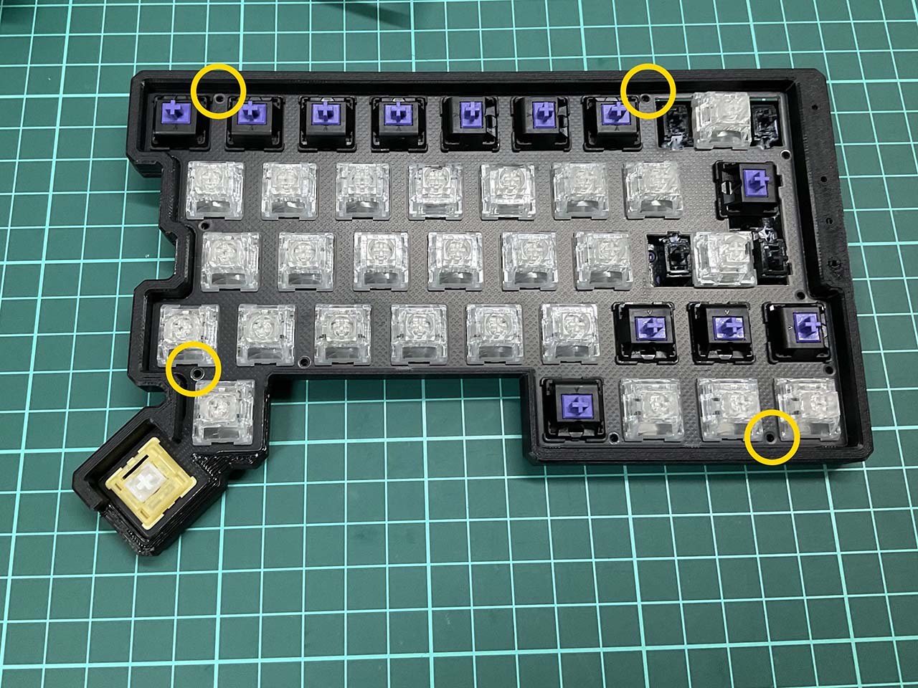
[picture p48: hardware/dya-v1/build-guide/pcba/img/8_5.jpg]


9. ゴム足の取り付け

ゴム足をケース裏側のへこみ部分４箇所に取り付けます

10. キーキャップの取り付け

キーキャップを取り付けて完成です。

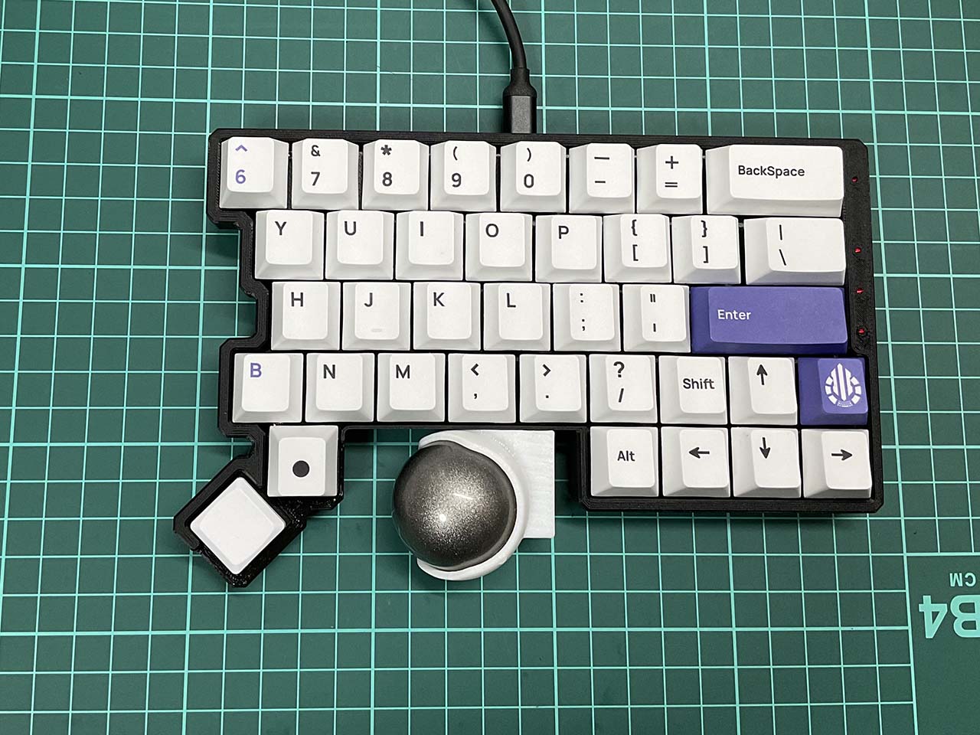
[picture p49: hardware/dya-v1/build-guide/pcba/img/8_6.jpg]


11. 左側の組み立て

右側同様に組み立ててください。FFC ケーブルでの接続がない分簡単です。
左側組み立て時にも右側でやったのと同様に USB 接続をすることで動作確認をすることができます。

12. 左右を接続して動作確認

- 左右の内側の USB ポートどうし（上寄りのポートどうし）を接続します
- 右の外側の USB ポートを PC と接続します

完成！

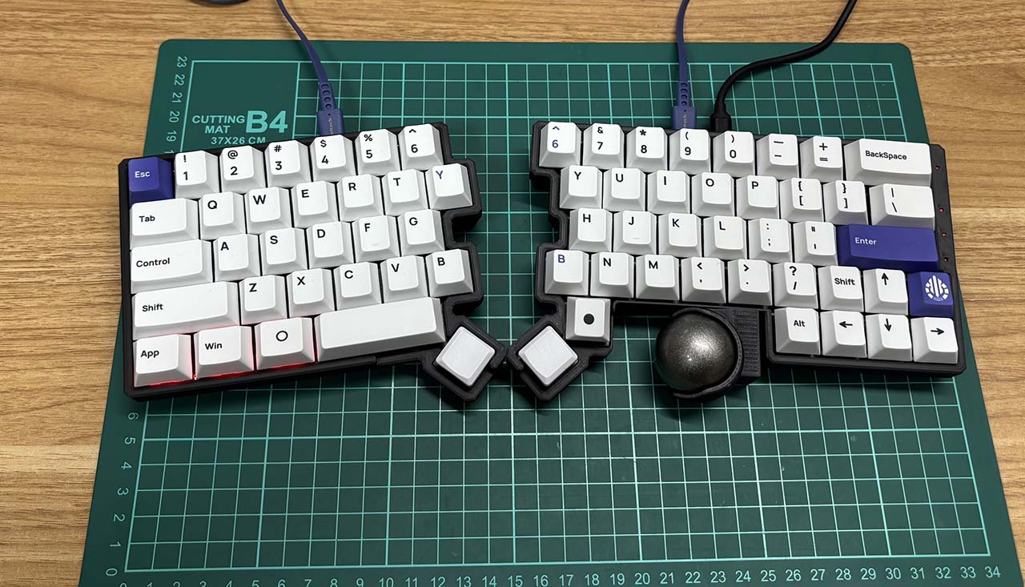
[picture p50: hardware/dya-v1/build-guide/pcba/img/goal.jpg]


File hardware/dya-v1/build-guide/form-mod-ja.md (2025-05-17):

# フォームを追加して静音性と打鍵音高める

どのくらい打鍵音が変わるかはこの動画を見てください https://youtu.be/V0h9aflH_0A

## 用意するもの

- [3mm PORON シート](https://www.amazon.co.jp/%E3%82%A4%E3%83%8E%E3%82%A2%E3%83%83%E3%82%AF-%E3%83%9D%E3%83%AD%E3%83%B3%E3%82%B9%E3%83%9D%E3%83%B3%E3%82%B8%E3%83%AD%E3%83%BC%E3%83%AB-5tX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)
- [PE シート](https://www.google.com/search?q=PE%E3%82%B7%E3%83%BC%E3%83%88) (キットの基板に巻かれていた緩衝材 or 100 均の梱包材コーナーなどで入手)
- [平刃デザインナイフ](https://www.amazon.co.jp/%E3%82%AA%E3%83%AB%E3%83%95%E3%82%A1-OLFA-%E3%82%A2%E3%83%BC%E3%83%88%E3%83%8A%E3%82%A4%E3%83%95%E3%83%97%E3%83%AD%E6%9B%BF%E5%88%83-%E3%83%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)
  - 普通のカッターナイフで切ろうとすると切断面がボロボロになってしまいがちです。
  - 平刃ナイフを横方向に動かさずに真上から切っていくことで断面が比較的綺麗に切れます。

PORON シートはケースの反響音、振動音を抑えます（たぶん）

PE シートはスイッチの反響音を高めてくれてそうです。パチパチ系のスイッチのポテンシャルを活かすためには必須です。

## 切る

PORON シートの上に基板/トッププレートを置いてその外形に沿うように平刃のナイフで上からザクザク切っていきます。

\*ザクザク: 普通のカッターのように歯を切りたい方向に引いて切るのではなく、平刃を真上から突き刺すようにして、１回のストロークで平刃の幅分だけ切る。平刃を切りたい方向に移動させながら何度も繰り返していく。結構根気のいる作業です。

### ボトムシート

- RP2040-Zero が付く部分は目分量でカットしました。
- 画像にはありませんが、FFC ケーブルを通す穴をいい感じの場所に開けた方がケーブルの取り回しがしやすいです。

| | | |
| --- | --- | --- |
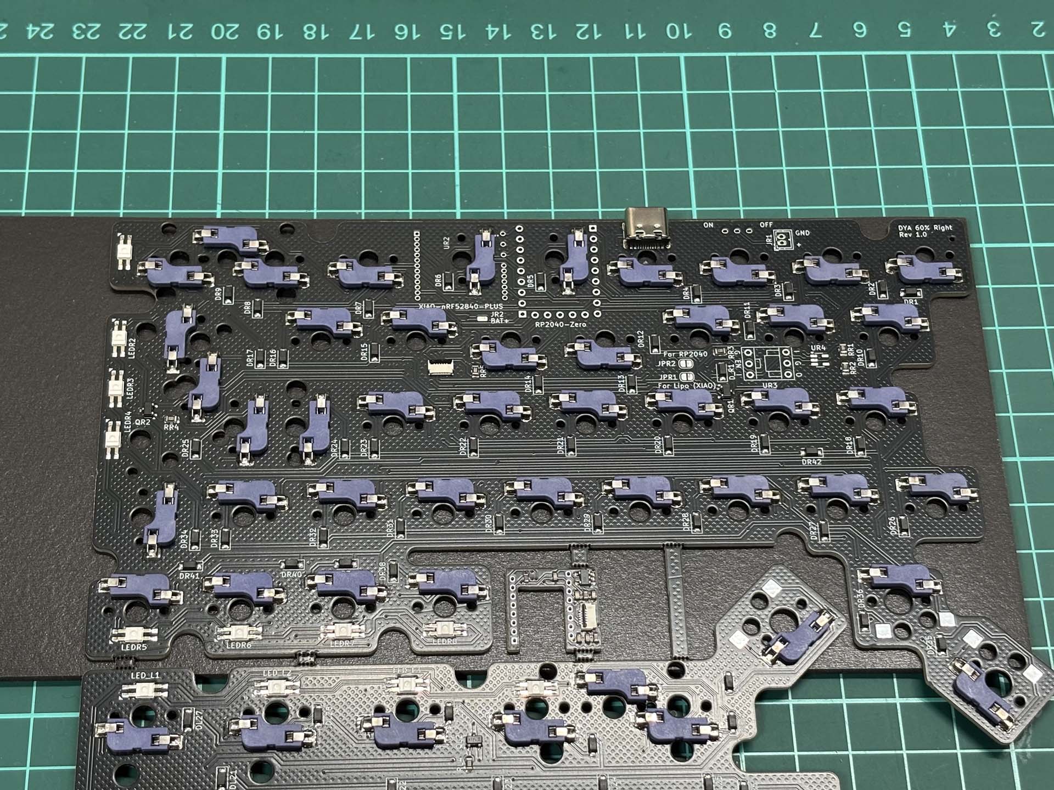
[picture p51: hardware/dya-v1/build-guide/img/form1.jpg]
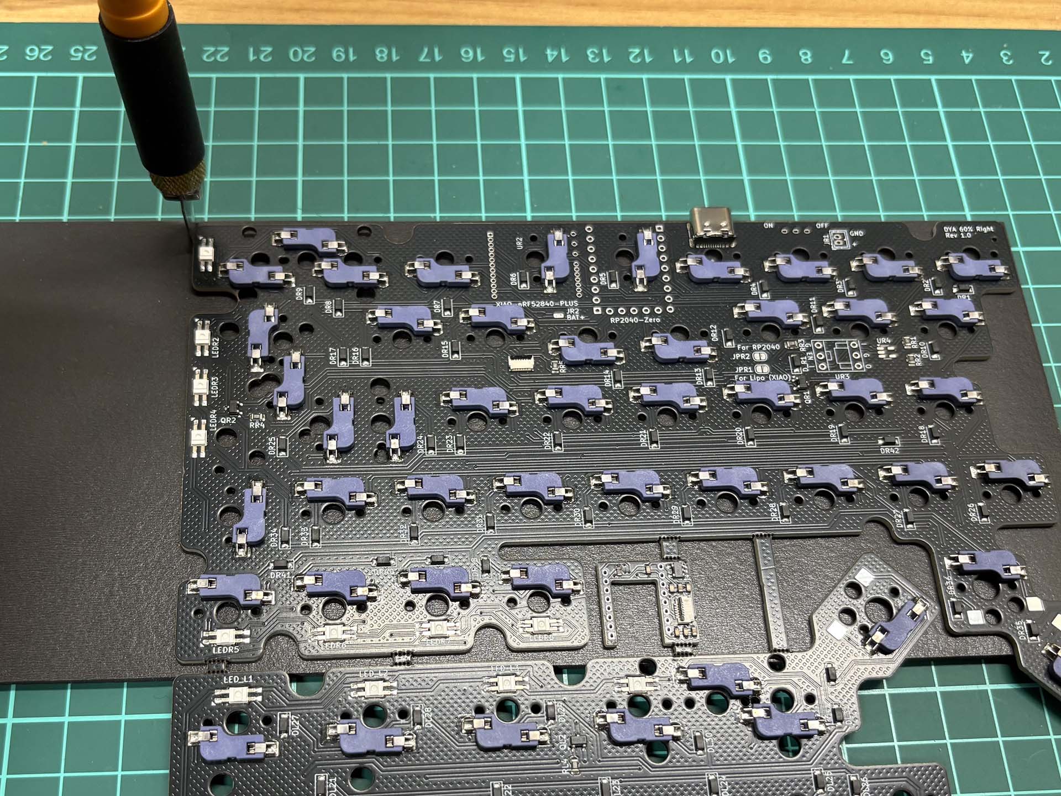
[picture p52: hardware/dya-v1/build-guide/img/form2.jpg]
|  |  |  |

### ミドルシート

基板とトッププレートの間を埋めるシートは以下のような感じに、トッププレートの下にシートを置いて、トッププレートの外形に合わせて切っていくと良いです。

最後の写真では基板の上で直接置いていますが、次のステップで間に PE フォームが挟まります。

| | | | |
| --- | --- | --- | --- |
|  |  |  |  |

### PE フォーム

基板と上で作ったミドルシートの間には PE フォームを引きます。
外形だけ合うようにはさみで適当にカットするだけで十分です。スイッチの穴を開ける必要はなく、このまま上からスイッチを押し込むことができます。ソケットの位置が分かりづらくなるので、**スイッチのピンの向きと穴の位置が合っているか注意しながら丁寧に押し込んでください。** スイッチのピンが曲がっていてたり、間違った向きでスイッチを押し込むと、ソケットが剥がれたりスイッチが壊れたりしてしまします。



## 組み立てる

これら３つのフォームを取り付けた状態で通常のガイドと同じように組み立てます。
3mm PORON シートは少し分厚いので、微妙にケースが閉まりきらなくなります。ネジを無理に強く締めすぎないように注意してください。

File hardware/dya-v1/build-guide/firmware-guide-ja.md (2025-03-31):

#  DYA v1.0 ファームウェアガイド

https://cormoran707.booth.pm/items/6705756 で配布中のキット向けのファームウェア書き込み/改造ガイドです。

## ファームウェア書き込み手順

1. [こちらのページ](https://github.com/cormoran/dya-keyboard/releases) から最新版のファームウェア（zip ファイル）をダウンロードしてください



2. RP2040-zero を PC に接続します

3. RP2040-zero の Boot スイッチと Reset スイッチを同時に押して、Reset スイッチ → Boot スイッチの順で離します。RP2040 がブートモードに入って PRI-PR2 という名前で USB メモリのようにデバイスが PC と接続されます。

   一度ファームウェアを書き込むと、キーボード組み立て後は右下から上に２番目のキーを押しながら Backspace キーを押すことでブートモードに入れるようになります。左右を接続した状態で左側の RP2040 を PC に接続していれば、この手順で左側もファームを更新できます。



4. 1 で解答したディレクトリに含まれるファームウェアファイルを USB メモリに移動させる要領で PRI-PR2 にコピーします。

   - `via.uf2` は VIA/Remap 対応のファームウェアです。デフォルトは US 配列ですが、[VIA](https://www.usevia.app/) or [Remap](https://remap-keys.app/) でノーコードでキー配列を変更できます。
     VIA, Remap で必要な json ファイルは [/firmware/qmk/keybaords/dya/dyya-via.json](https://github.com/cormoran/dya-keyboard/blob/main/firmware/qmk/keyboards/dya/dya-via.json) に置いています。
   - `dya_us.uf2`, `dya_jis.uf2` は VIA 未対応の US, JIS 配列ファームウェアです。
   - デフォルトの配列は Mac で使用することを想定した配列になっています。Windows ユーザーの方は VIA 対応ファームウェアをインストールして自分好みに設定を変更してみてください。

## デフォルトの配列

デフォルトでは４つのレイヤーが定義されています

### layer0: デフォルト

左右親指は日本語/英語入力を切り替えるために Mac の英かな + long press で Cmd が割り当てられています。

Windows 向けの便利な配列は気が向いたらそのうち考えます。要望が強ければ教えてください。



### layer1: トラックボールを動かした時に有効化されるレイヤー

トラックボールを動かすと自動で有効化されて、動かすのをやめると一定時間後に無効化されるレイヤーです

マウスの左右クリックなどが割り当てられています

- J: 左クリック
- K: 右クリック
- L: 押している間 layer1 維持
- `;` or 左手親指: 押している間 layer2 (スクロール) に移動
- n, m: 戻る、進む

n, m の戻る/進むは間違って発動してしまうことが多いので邪魔なら VIA で上書きしてください。



### layer2: スクロールレイヤー

このレイヤーが有効な間、トラックボールはスクロールモードになります。

### layer3: 設定レイヤー

LED、ブートモードなどの設定が割り当てられたレイヤーです

右下から上に２番目のキーを押している間有効になります。

配列は以下の図を見てください。音量変更とミュートが便利です。

余っているキーが多いのでよく使うショートカットをこのレイヤーに当てはめると便利です



## VIA の使い方

1. https://www.usevia.app/settings を開いて、"Show Design tab" を ON にします



2. https://www.usevia.app/design を開いて、[/firmware/qmk/keybaords/dya/dyya-via.json](https://github.com/cormoran/dya-keyboard/blob/main/firmware/qmk/keyboards/dya/dya-via.json) をドロップします



3. キーボードを PC に接続し、https://www.usevia.app/ からキーボードに接続します

   好きなように配列をカスタマイズしてみてください



4. ひとまず LED ライトの色を変えてみると楽しいかもしれません

   VIA の一番左下のライトアイコンをクリックすると LED バックライトの設定画面に移ります。明るさや色を調整してみてください。



## remap の使い方

基本的には VIA と同じです。
キーボードを接続して、[/firmware/qmk/keybaords/dya/dyya-via.json](https://github.com/cormoran/dya-keyboard/blob/main/firmware/qmk/keyboards/dya/dya-via.json) をアップロードしてください。
現在キーボードを登録申請しているので、申請が受理されれば json ファイルのアップロードは不要になると思います。

## QMK ソースコードの書き換え

ファームウェアは、このレポジトリで管理されている DYA の設定コードと、QMK ファームウェアのソースコードを使ってビルドされています。

詳細は [Makefile](https://github.com/cormoran/dya-keyboard/blob/main/Makefile) を見てもらえるとわかると思います。

簡単に要点を書いておくと、

- https://github.com/cormoran/dya-keyboard/tree/main/firmware/qmk/keyboards/dya に QMK の keyboards 以下に入るべき DYA のソースコードがあります。細かな設定や配列の定義、PMW3610 の DYA 向けドライバが含まれています。
- `make init` するとこのレポジトリの submodule として qmk_firmware のソースコードがダウンロードされます
- `make compile` とすると、`firmware/qmk/keyboards/dya` が `firmware/qmk_firmware` 以下にコピーされて dya をターゲットにした QMK ビルドが始まります

  デフォルトでは US 配列(`KM=default`)がビルドされます。VIA 対応ビルドをするためには `make compile KM=via` と指定します

- `make flash KM=via` とすると、ブートモードで PC に接続された RP2040 にファームウェアが書き込まれます

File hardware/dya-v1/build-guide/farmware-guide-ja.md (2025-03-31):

#  DYA v1.0 ファームウェアガイド

https://cormoran707.booth.pm/items/6705756 で配布中のキット向けのファームウェア書き込み/改造ガイドです。

## ファームウェア書き込み手順

1. [こちらのページ](https://github.com/cormoran/dya-keyboard/releases) から最新版のファームウェア（zip ファイル）をダウンロードしてください



2. RP2040-zero を PC に接続します

3. RP2040-zero の Boot スイッチと Reset スイッチを同時に押して、Reset スイッチ → Boot スイッチの順で離します。RP2040 がブートモードに入って PRI-PR2 という名前で USB メモリのようにデバイスが PC と接続されます。

   一度ファームウェアを書き込むと、キーボード組み立て後は右下から上に２番目のキーを押しながら Backspace キーを押すことでブートモードに入れるようになります。左右を接続した状態で左側の RP2040 を PC に接続していれば、この手順で左側もファームを更新できます。



4. 1 で解答したディレクトリに含まれるファームウェアファイルを USB メモリに移動させる要領で PRI-PR2 にコピーします。

   - `via.uf2` は VIA/Remap 対応のファームウェアです。デフォルトは US 配列ですが、[VIA](https://www.usevia.app/) or [Remap](https://remap-keys.app/) でノーコードでキー配列を変更できます。
     VIA, Remap で必要な json ファイルは [/farms/qmk/keybaords/dya/dyya-via.json](https://github.com/cormoran/dya-keyboard/blob/main/farms/qmk/keyboards/dya/dya-via.json) に置いています。
   - `dya_us.uf2`, `dya_jis.uf2` は VIA 未対応の US, JIS 配列ファームウェアです。
   - デフォルトの配列は Mac で使用することを想定した配列になっています。Windows ユーザーの方は VIA 対応ファームウェアをインストールして自分好みに設定を変更してみてください。

## デフォルトの配列

デフォルトでは４つのレイヤーが定義されています

### layer0: デフォルト

左右親指は日本語/英語入力を切り替えるために Mac の英かな + long press で Cmd が割り当てられています。

Windows 向けの便利な配列は気が向いたらそのうち考えます。要望が強ければ教えてください。



### layer1: トラックボールを動かした時に有効化されるレイヤー

トラックボールを動かすと自動で有効化されて、動かすのをやめると一定時間後に無効化されるレイヤーです

マウスの左右クリックなどが割り当てられています

- J: 左クリック
- K: 右クリック
- L: 押している間 layer1 維持
- `;` or 左手親指: 押している間 layer2 (スクロール) に移動
- n, m: 戻る、進む

n, m の戻る/進むは間違って発動してしまうことが多いので邪魔なら VIA で上書きしてください。



### layer2: スクロールレイヤー

このレイヤーが有効な間、トラックボールはスクロールモードになります。

### layer3: 設定レイヤー

LED、ブートモードなどの設定が割り当てられたレイヤーです

右下から上に２番目のキーを押している間有効になります。

配列は以下の図を見てください。音量変更とミュートが便利です。

余っているキーが多いのでよく使うショートカットをこのレイヤーに当てはめると便利です



## VIA の使い方

1. https://www.usevia.app/settings を開いて、"Show Design tab" を ON にします



2. https://www.usevia.app/design を開いて、[/farms/qmk/keybaords/dya/dyya-via.json](https://github.com/cormoran/dya-keyboard/blob/main/farms/qmk/keyboards/dya/dya-via.json) をドロップします



3. キーボードを PC に接続し、https://www.usevia.app/ からキーボードに接続します

   好きなように配列をカスタマイズしてみてください



4. ひとまず LED ライトの色を変えてみると楽しいかもしれません

   VIA の一番左下のライトアイコンをクリックすると LED バックライトの設定画面に移ります。明るさや色を調整してみてください。



## remap の使い方

基本的には VIA と同じです。
キーボードを接続して、[/farms/qmk/keybaords/dya/dyya-via.json](https://github.com/cormoran/dya-keyboard/blob/main/farms/qmk/keyboards/dya/dya-via.json) をアップロードしてください。
現在キーボードを登録申請しているので、申請が受理されれば json ファイルのアップロードは不要になると思います。

## QMK ソースコードの書き換え

ファームウェアは、このレポジトリで管理されている DYA の設定コードと、QMK ファームウェアのソースコードを使ってビルドされています。

詳細は [Makefile](https://github.com/cormoran/dya-keyboard/blob/main/Makefile) を見てもらえるとわかると思います。

簡単に要点を書いておくと、

- https://github.com/cormoran/dya-keyboard/tree/main/farms/qmk/keyboards/dya に QMK の keyboards 以下に入るべき DYA のソースコードがあります。細かな設定や配列の定義、PMW3610 の DYA 向けドライバが含まれています。
- `make init` するとこのレポジトリの submodule として qmk_firmware のソースコードがダウンロードされます
- `make compile` とすると、`farms/qmk/keyboards/dya` が `farms/qmk_firmware` 以下にコピーされて dya をターゲットにした QMK ビルドが始まります

  デフォルトでは US 配列(`KM=default`)がビルドされます。VIA 対応ビルドをするためには `make compile KM=via` と指定します

- `make flash KM=via` とすると、ブートモードで PC に接続された RP2040 にファームウェアが書き込まれます

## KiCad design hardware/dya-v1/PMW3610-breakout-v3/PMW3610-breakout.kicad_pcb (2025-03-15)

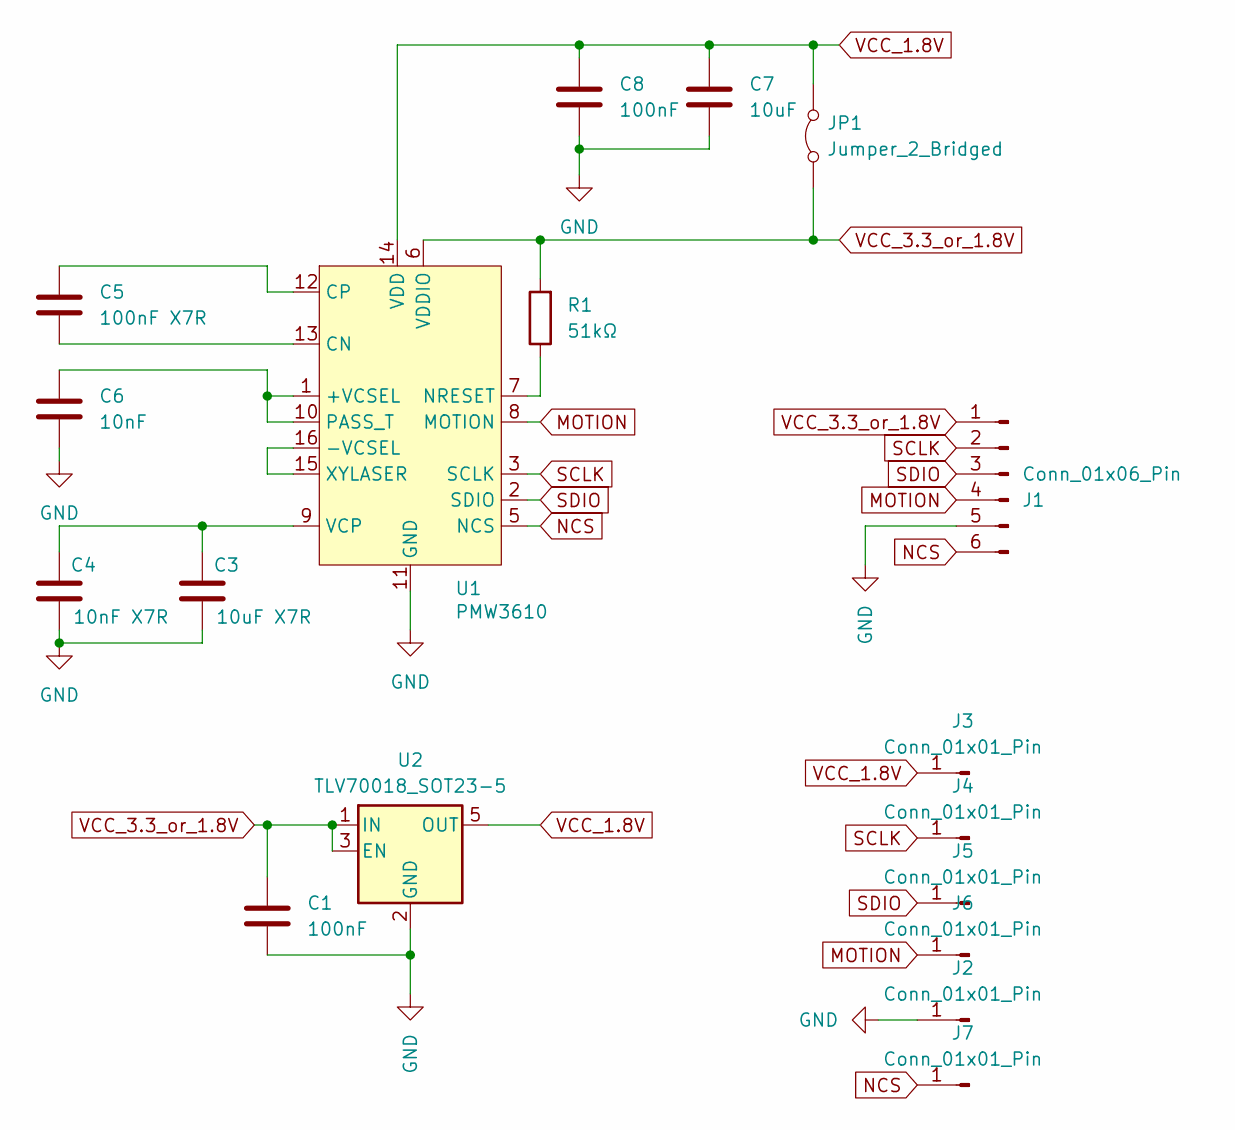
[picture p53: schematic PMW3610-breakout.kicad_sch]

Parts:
C1, C8: 100nF; C_0603_1608Metric; LCSC C14663
C3: 10uF X7R; C_0603_1608Metric; LCSC C19702
C4: 10nF X7R; C_0603_1608Metric; LCSC C57112
C5: 100nF X7R; C_0603_1608Metric; LCSC C14663
C6: 10nF; C_0603_1608Metric; LCSC C57112
C7: 10uF; C_0603_1608Metric; LCSC C19702
J1: Conn_01x06_Pin; JUSHUO-AFH34-S06FIA-1H; LCSC C5139821
J2, J3, J4, J5, J6, J7: Conn_01x01_Pin; TestPoint_Pad_D1.0mm
JP1: Jumper_2_Bridged; SolderJumper-2_P1.3mm_Open_RoundedPad1.0x1.5mm
R1: 51kΩ; R_0603_1608Metric; LCSC C23196
U1: PMW3610; PMW3610DM-SUDU 16Pin
U2: TLV70018_SOT23-5; SOT-23-5

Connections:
GND: C1.2, C3.2, C4.2, C6.2, C7.2, C8.2, J1.5, J2.1, U1.11 (GND), U2.2 (GND)
MOTION: J1.4, J6.1, U1.8 (MOTION)
NCS: J1.6, J7.1, U1.5 (NCS)
unnamed: C6.1, U1.1 (+VCSEL), U1.10 (PASS_T)
unnamed: U1.15 (XYLASER), U1.16 (-VCSEL)
unnamed: C5.2, U1.13 (CN)
unnamed: C5.1, U1.12 (CP)
unnamed: R1.1, U1.7 (NRESET)
unnamed: C3.1, C4.1, U1.9 (VCP)
SCLK: J1.2, J4.1, U1.3 (SCLK)
SDIO: J1.3, J5.1, U1.2 (SDIO)
VCC_1.8V: C7.1, C8.1, J3.1, JP1.2 (B), U1.14 (VDD), U2.5 (OUT)
VCC_3.3_or_1.8V: C1.1, J1.1, JP1.1 (A), R1.2, U1.6 (VDDIO), U2.1 (IN), U2.3 (EN)

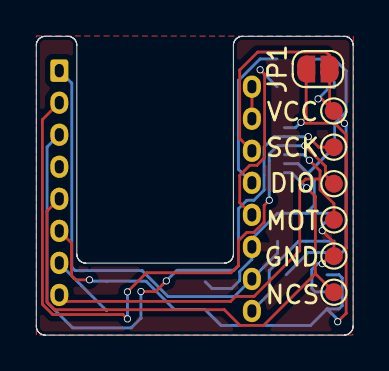
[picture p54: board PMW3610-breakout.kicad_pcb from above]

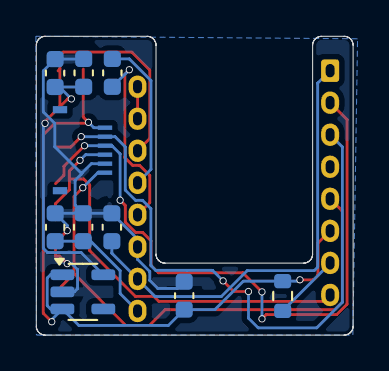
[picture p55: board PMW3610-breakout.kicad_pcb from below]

Board: 2 copper layers, 17.6 x 16.6 mm, 18 parts (10 on the bottom side), 13 nets.

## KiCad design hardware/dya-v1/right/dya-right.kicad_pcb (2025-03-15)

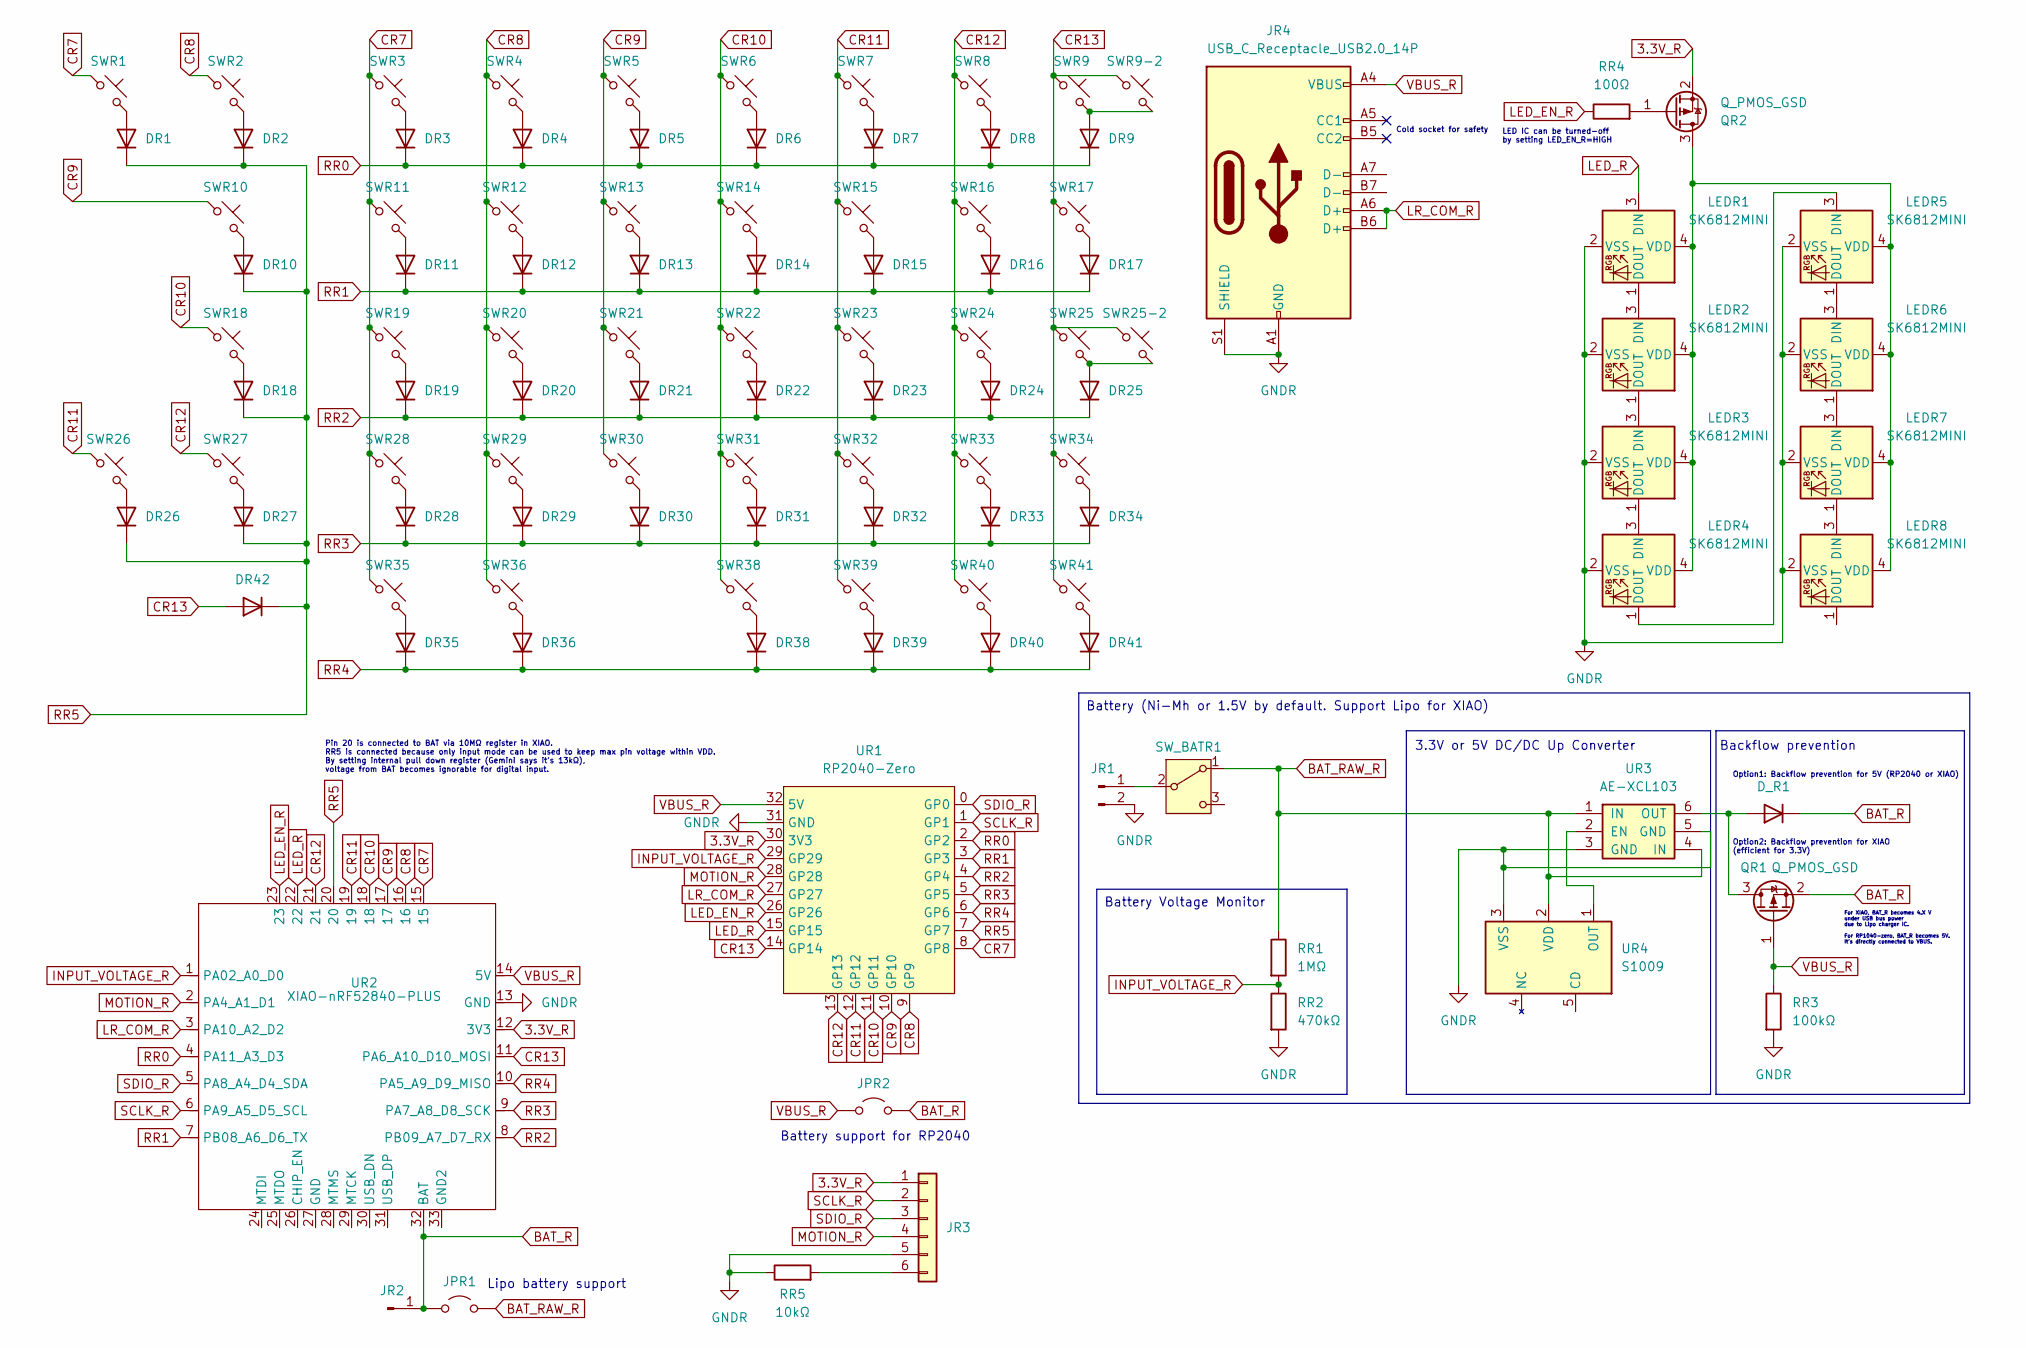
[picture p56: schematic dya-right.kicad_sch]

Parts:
DR1, DR2, DR3, DR4, DR5, DR6, DR7, DR8, DR9, DR10, DR11, DR12, DR13, DR14, DR15, DR16, DR17, DR18, DR19, DR20, DR21, DR22, DR23, DR24, DR25, DR26, DR27, DR28, DR29, DR30, DR31, DR32, DR33, DR34, DR35, DR36, DR38, DR39, DR40, DR41, DR42: D; D_SOD-123; LCSC C81598
D_R1: D; D_SOD-123; LCSC C81598
JPR1, JPR2: Jumper_2_Open; SolderJumper-2_P1.3mm_Open_RoundedPad1.0x1.5mm
JR1: Conn_01x02_Pin; JST_ZH_B2B-ZR_1x02_P1.50mm_Vertical
JR2: Conn_01x01_Pin; SolderWirePad_1x01_SMD_1x2mm
JR3: Conn_01x04; JUSHUO-AFH34-S06FIA-1H; LCSC C5139821
JR4: USB_C_Receptacle_USB2.0_14P; USB_C_Receptacle_G-Switch_GT-USB-7010ASV; LCSC C2927038
LEDR1, LEDR2, LEDR3, LEDR4, LEDR5, LEDR6, LEDR7, LEDR8: SK6812MINI; LED_SK6812MINI-E_BL; LCSC C5149201
QR1, QR2: Q_PMOS_GSD; SOT-23; LCSC C15127
RR1: 1MΩ; R_0805_2012Metric; LCSC C17514
RR2: 470kΩ; R_0805_2012Metric; LCSC C17709
RR3: 100kΩ; R_0805_2012Metric; LCSC C149504
RR4: 100Ω; R_0805_2012Metric; LCSC C17408
RR5: 10kΩ; R_0805_2012Metric; LCSC C17414
SWR1, SWR2, SWR3, SWR4, SWR5, SWR6, SWR7, SWR8, SWR9, SWR10, SWR11, SWR12, SWR13, SWR14, SWR15, SWR16, SWR17, SWR18, SWR19, SWR20, SWR21, SWR22, SWR23, SWR24, SWR26, SWR27, SWR28, SWR29, SWR30, SWR31, SWR32, SWR33, SWR34, SWR38, SWR39, SWR40, SWR41: SW_Push_45deg; MX-Hotswap-1U
SWR9-2: SW_Push_45deg; MX-Hotswap-2U
SWR25: SW_Push_45deg; MX-Hotswap-2.25U-ReversedStabilizers
SWR25-2: SW_Push_45deg; MX-Hotswap-ISO
SWR35, SWR36: SW_Push_45deg; MX-KailhChocV2-Hybrid-Hotswap-1U
SW_BATR1: SW_SPDT; TGSW_MSK-12D19
UR1: RP2040-Zero
UR2: XIAO-nRF52840-PLUS; XIAO_nRF52840_plus
UR3: AE-XCL103
UR4: S1009; SOT-23-5

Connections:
3.3V_R: JR3.1, QR2.2 (S), UR1.30 (3V3), UR2.12 (3V3)
BAT_R: D_R1.1 (K), JPR1.1 (A), JPR2.2 (B), JR2.1, QR1.2 (S), UR2.32 (BAT)
BAT_RAW_R: JPR1.2 (B), RR1.1, SW_BATR1.1 (A), UR3.1 (IN), UR3.4 (IN), UR4.2 (VDD)
CR7: SWR1.1, SWR3.1, SWR11.1, SWR19.1, SWR28.1, SWR35.1, UR1.8 (GP8), UR2.15
CR8: SWR2.1, SWR4.1, SWR12.1, SWR20.1, SWR29.1, SWR36.1, UR1.9 (GP9), UR2.16
CR9: SWR5.1, SWR10.1, SWR13.1, SWR21.1, SWR30.1, UR1.10 (GP10), UR2.17
CR10: SWR6.1, SWR14.1, SWR18.1, SWR22.1, SWR31.1, SWR38.1, UR1.11 (GP11), UR2.18
CR11: SWR7.1, SWR15.1, SWR23.1, SWR26.1, SWR32.1, SWR39.1, UR1.12 (GP12), UR2.19
CR12: SWR8.1, SWR16.1, SWR24.1, SWR27.1, SWR33.1, SWR40.1, UR1.13 (GP13), UR2.21
CR13: DR42.2 (A), SWR9.1, SWR9-2.1, SWR17.1, SWR25.1, SWR25-2.1, SWR34.1, SWR41.1, UR1.14 (GP14), UR2.11 (PA6_A10_D10_MOSI)
GNDR: JR1.2, JR3.5, JR4.A1 (GND), JR4.A12 (GND), JR4.B1 (GND), JR4.B12 (GND), JR4.S1 (SHIELD), LEDR1.2 (VSS), LEDR2.2 (VSS), LEDR3.2 (VSS), LEDR4.2 (VSS), LEDR5.2 (VSS), LEDR6.2 (VSS), LEDR7.2 (VSS), LEDR8.2 (VSS), RR2.2, RR3.2, RR5.1, UR1.31 (GND), UR2.13 (GND), UR3.3 (GND), UR3.5 (GND), UR4.3 (VSS)
INPUT_VOLTAGE_R: RR1.2, RR2.1, UR1.29 (GP29), UR2.1 (PA02_A0_D0)
LED_EN_R: RR4.1, UR1.26 (GP26), UR2.23
LED_R: LEDR1.3 (DIN), UR1.15 (GP15), UR2.22
LR_COM_R: JR4.A6 (D+), JR4.B6 (D+), UR1.27 (GP27), UR2.3 (PA10_A2_D2)
MOTION_R: JR3.4, UR1.28 (GP28), UR2.2 (PA4_A1_D1)
unnamed: DR1.2 (A), SWR1.2
unnamed: DR2.2 (A), SWR2.2
unnamed: DR3.2 (A), SWR3.2
unnamed: DR4.2 (A), SWR4.2
unnamed: DR5.2 (A), SWR5.2
unnamed: DR6.2 (A), SWR6.2
unnamed: DR7.2 (A), SWR7.2
unnamed: DR8.2 (A), SWR8.2
unnamed: DR9.2 (A), SWR9.2, SWR9-2.2
unnamed: DR10.2 (A), SWR10.2
unnamed: DR11.2 (A), SWR11.2
unnamed: DR12.2 (A), SWR12.2
unnamed: DR13.2 (A), SWR13.2
unnamed: DR14.2 (A), SWR14.2
unnamed: DR15.2 (A), SWR15.2
unnamed: DR16.2 (A), SWR16.2
unnamed: DR17.2 (A), SWR17.2
unnamed: DR18.2 (A), SWR18.2
unnamed: DR19.2 (A), SWR19.2
unnamed: DR20.2 (A), SWR20.2
unnamed: DR21.2 (A), SWR21.2
unnamed: DR22.2 (A), SWR22.2
unnamed: DR23.2 (A), SWR23.2
unnamed: DR24.2 (A), SWR24.2
unnamed: DR25.2 (A), SWR25.2, SWR25-2.2
unnamed: DR26.2 (A), SWR26.2
unnamed: DR27.2 (A), SWR27.2
unnamed: DR28.2 (A), SWR28.2
unnamed: DR29.2 (A), SWR29.2
unnamed: DR30.2 (A), SWR30.2
unnamed: DR31.2 (A), SWR31.2
unnamed: DR32.2 (A), SWR32.2
unnamed: DR33.2 (A), SWR33.2
unnamed: DR34.2 (A), SWR34.2
unnamed: DR35.2 (A), SWR35.2
unnamed: DR36.2 (A), SWR36.2
unnamed: DR38.2 (A), SWR38.2
unnamed: DR39.2 (A), SWR39.2
unnamed: DR40.2 (A), SWR40.2
unnamed: DR41.2 (A), SWR41.2
unnamed: D_R1.2 (A), QR1.3 (D), UR3.6 (OUT)
unnamed: JR1.1, SW_BATR1.2 (B)
unnamed: JR3.6, RR5.2
unnamed: LEDR1.1 (DOUT), LEDR2.3 (DIN)
unnamed: LEDR1.4 (VDD), LEDR2.4 (VDD), LEDR3.4 (VDD), LEDR4.4 (VDD), LEDR5.4 (VDD), LEDR6.4 (VDD), LEDR7.4 (VDD), LEDR8.4 (VDD), QR2.3 (D)
unnamed: LEDR2.1 (DOUT), LEDR3.3 (DIN)
unnamed: LEDR3.1 (DOUT), LEDR4.3 (DIN)
unnamed: LEDR4.1 (DOUT), LEDR5.3 (DIN)
unnamed: LEDR5.1 (DOUT), LEDR6.3 (DIN)
unnamed: LEDR6.1 (DOUT), LEDR7.3 (DIN)
unnamed: LEDR7.1 (DOUT), LEDR8.3 (DIN)
unnamed: QR2.1 (G), RR4.2
unnamed: UR3.2 (EN), UR4.1 (OUT)
RR0: DR3.1 (K), DR4.1 (K), DR5.1 (K), DR6.1 (K), DR7.1 (K), DR8.1 (K), DR9.1 (K), UR1.2 (GP2), UR2.4 (PA11_A3_D3)
RR1: DR11.1 (K), DR12.1 (K), DR13.1 (K), DR14.1 (K), DR15.1 (K), DR16.1 (K), DR17.1 (K), UR1.3 (GP3), UR2.7 (PB08_A6_D6_TX)
RR2: DR19.1 (K), DR20.1 (K), DR21.1 (K), DR22.1 (K), DR23.1 (K), DR24.1 (K), DR25.1 (K), UR1.4 (GP4), UR2.8 (PB09_A7_D7_RX)
RR3: DR28.1 (K), DR29.1 (K), DR30.1 (K), DR31.1 (K), DR32.1 (K), DR33.1 (K), DR34.1 (K), UR1.5 (GP5), UR2.9 (PA7_A8_D8_SCK)
RR4: DR35.1 (K), DR36.1 (K), DR38.1 (K), DR39.1 (K), DR40.1 (K), DR41.1 (K), UR1.6 (GP6), UR2.10 (PA5_A9_D9_MISO)
RR5: DR1.1 (K), DR2.1 (K), DR10.1 (K), DR18.1 (K), DR26.1 (K), DR27.1 (K), DR42.1 (K), UR1.7 (GP7), UR2.20
SCLK_R: JR3.2, UR1.1 (GP1), UR2.6 (PA9_A5_D5_SCL)
SDIO_R: JR3.3, UR1.0 (GP0), UR2.5 (PA8_A4_D4_SDA)
VBUS_R: JPR2.1 (A), JR4.A4 (VBUS), JR4.A9 (VBUS), JR4.B4 (VBUS), JR4.B9 (VBUS), QR1.1 (G), RR3.1, UR1.32 (5V), UR2.14 (5V)

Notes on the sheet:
Option1: Backflow prevention for 5V (RP2040 or XIAO)
Battery (Ni-Mh or 1.5V by default. Support Lipo for XIAO)
Pin 20 is connected to BAT via 10MΩ register in XIAO. RR5 is connected because only input mode can be used to keep max pin voltage within VDD. By setting internal pull down register (Gemini says it's 13kΩ), voltage from BAT becomes ignorable for digital input.
Cold socket for safety
3.3V or 5V DC/DC Up Converter
For XIAO, BAT_R becomes 4.X V under USB bus power due to Lipo charger IC. For RP1040-zero, BAT_R becomes 5V. It's directly connected to VBUS.
Backflow prevention
Battery support for RP2040
LED IC can be turned-off by setting LED_EN_R=HIGH
Battery Voltage Monitor
Option2: Backflow prevention for XIAO (efficient for 3.3V)
Lipo battery support

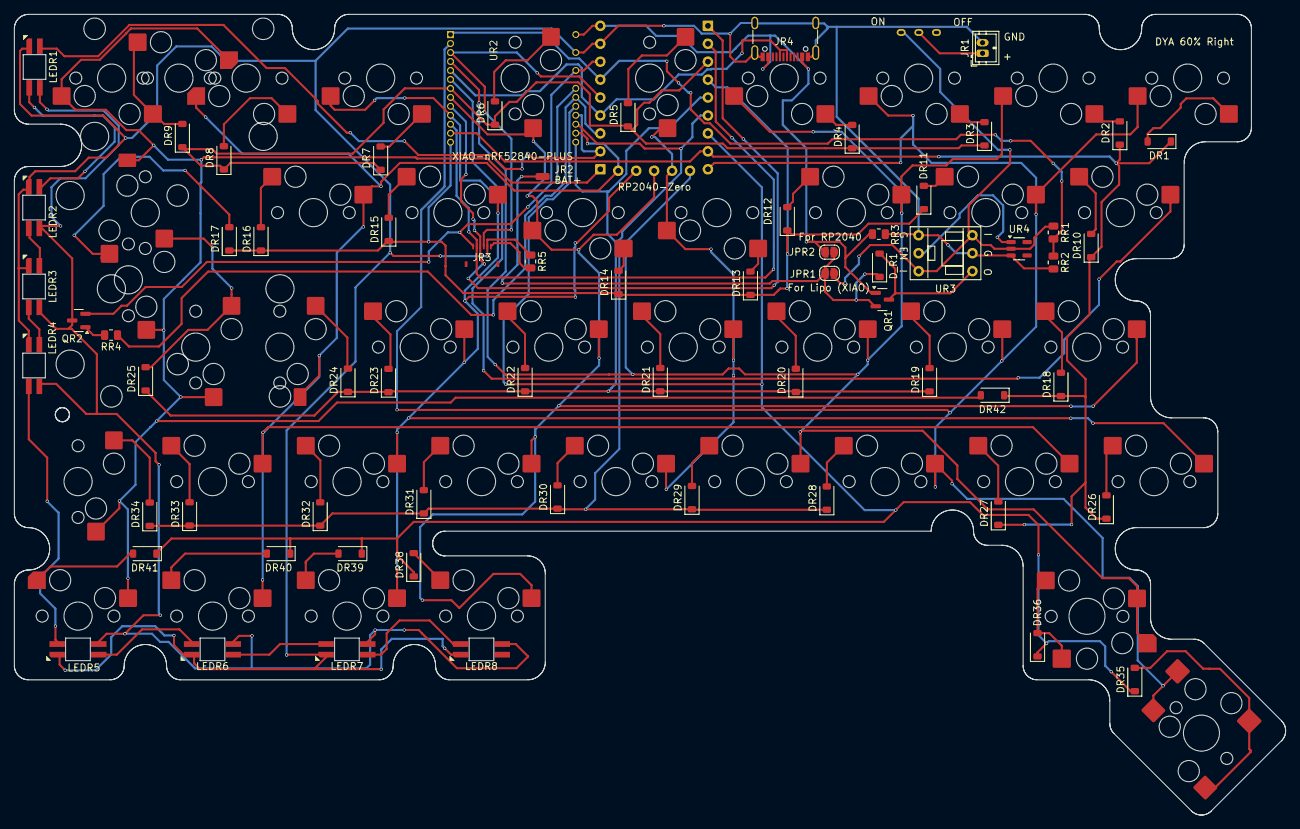
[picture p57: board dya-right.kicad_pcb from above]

Board: 2 copper layers, 180.1 x 113.4 mm, 110 parts (1 on the bottom side), 78 nets.

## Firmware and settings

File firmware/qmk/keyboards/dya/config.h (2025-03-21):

// Copyright 2025 cormoran707
// SPDX-License-Identifier: GPL-2.0-or-later
#pragma once

#ifndef SERIAL_NUMBER
#    define SERIAL_NUMBER "cormoran.me:dya:v1.0.0:0"
#endif

#define SERIAL_PIO_USE_PIO1
#define WS2812_DI_PIN GP15

#define BOOTMAGIC_ROW_RIGHT 6
#define BOOTMAGIC_COLUMN_RIGHT 6

#define POINTING_DEVICE_RIGHT
#define POINTING_DEVICE_CS_PIN NO_PIN
#define POINTING_DEVICE_SCLK_PIN GP1
#define POINTING_DEVICE_SDIO_PIN GP0
// Not supported for split keyboard
// #define POINTING_DEVICE_MOTION_PIN GP28

#define POINTING_DEVICE_MOTION_PIN_ACTIVE_LOW

#define SPLIT_POINTING_ENABLE
#define POINTING_DEVICE_INVERT_Y

#define POINTING_DEVICE_AUTO_MOUSE_ENABLE

#define HOLD_ON_OTHER_KEY_PRESS

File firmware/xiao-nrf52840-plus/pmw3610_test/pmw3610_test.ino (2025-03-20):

#include <Adafruit_TinyUSB.h>

#include "dya-xiao-nrf52840-plus.h"
#include "pmw3610.h"

#define BIT(i) (1 << i)
#define TOINT16(val, bits) (((struct { int16_t value : bits; }){val}).value)

static uint8_t reg_read(uint8_t reg_address) {
    pinMode(DYA_PIN_SDIO, OUTPUT);
    for (int8_t i = 7; i >= 0; i--) {
        digitalWrite(DYA_PIN_SCLK, 0);
        digitalWrite(DYA_PIN_SDIO, reg_address & BIT(i));
        delayMicroseconds(1);
        digitalWrite(DYA_PIN_SCLK, 1);
        delayMicroseconds(1);
    }
    pinMode(DYA_PIN_SDIO, INPUT);
    delayMicroseconds(T_SRAD);
    uint8_t r = 0;
    for (int8_t i = 7; i >= 0; i--) {
        digitalWrite(DYA_PIN_SCLK, 0);
        delayMicroseconds(1);
        digitalWrite(DYA_PIN_SCLK, 1);
        delayMicroseconds(1);
        r |= digitalRead(DYA_PIN_SDIO) << i;
    }
    delayMicroseconds(10);
    return r;
}

void _reg_write(uint8_t reg_address, uint8_t data) {
    reg_address |= PMW3610_WRITE_BIT;

    pinMode(DYA_PIN_SDIO, OUTPUT);
    for (int8_t i = 7; i >= 0; i--) {
        digitalWrite(DYA_PIN_SCLK, 0);
        digitalWrite(DYA_PIN_SDIO, reg_address & BIT(i));
        delayMicroseconds(1);
        digitalWrite(DYA_PIN_SCLK, 1);
        delayMicroseconds(1);
    }
    for (int8_t i = 7; i >= 0; i--) {
        digitalWrite(DYA_PIN_SCLK, 0);
        digitalWrite(DYA_PIN_SDIO, data & BIT(i));
        delayMicroseconds(1);
        digitalWrite(DYA_PIN_SCLK, 1);
        delayMicroseconds(1);
    }
    delayMicroseconds(T_SCLK_NCS_WR);
    delayMicroseconds(T_SWX);
}

void reg_write(uint8_t reg_address, uint8_t data) {
    _reg_write(PMW3610_REG_SPI_CLK_ON_REQ, PMW3610_SPI_CLOCK_CMD_ENABLE);
    _reg_write(reg_address, data);
    _reg_write(PMW3610_REG_SPI_CLK_ON_REQ, PMW3610_SPI_CLOCK_CMD_DISABLE);
}

void set_cpi(uint32_t cpi) {
    uint8_t value = cpi / 200;
    reg_write(PMW3610_REG_SPI_PAGE0, 0xFF);
    reg_write(PMW3610_REG_RES_STEP, value);
    reg_write(PMW3610_REG_SPI_PAGE1, 0x00);
}

void setup() {
    Serial.begin(38400);
    pinMode(DYA_PIN_SCLK, OUTPUT);
    pinMode(DYA_PIN_SDIO, OUTPUT);
    pinMode(DYA_PIN_MOTION, INPUT);

    delay(1000);
    init_pmw3610();
}

void init_pmw3610() {
    Serial.println("Initializing PMW3610");
    reg_write(PMW3610_REG_POWER_UP_RESET, PMW3610_POWERUP_CMD_RESET);

    delay(50);
    reg_write(PMW3610_REG_OBSERVATION, 0x00);

    delay(10);
    uint8_t obs = reg_read(PMW3610_REG_OBSERVATION);
    if ((obs & 0x0F) != 0x0F) {
        Serial.println("observation is wrong");
    }
    for (int i = 0; i < 10; i++) {
        Serial.write("* Product Id = ");
        Serial.println(reg_read(PMW3610_REG_PRODUCT_ID));
        Serial.write("* Revision Id = ");
        Serial.println(reg_read(PMW3610_REG_REVISION_ID));
    }

    reg_write(PMW3610_REG_PERFORMANCE,
              0x0d);  // normal operation, 4ms, 4ms, 4ms
    // Time after which sensor goes from RUN to REST1 mode.
    reg_write(PMW3610_REG_RUN_DOWNSHIFT,
              0x04);  // 128ms (unit: pos-rate (4ms) * 8 = 32ms)
    reg_write(PMW3610_REG_REST1_PERIOD, 0x04);  // 40ms (unit: 10ms)
    reg_write(PMW3610_REG_REST1_DOWNSHIFT,
              0x0f);  // (unit: 16 * Rest1_sample_period (above, 40ms))

    set_cpi(200);

    delay(50);

    reg_read(PMW3610_REG_MOTION);
    reg_read(PMW3610_REG_DELTA_X_L);
    reg_read(PMW3610_REG_DELTA_Y_L);
    reg_read(PMW3610_REG_DELTA_XY_H);
}

void loop() {
    if (Serial.available()) {
        String s = Serial.readString();
        if (s.startsWith("reset")) {
            init_pmw3610();
        }
    }
    uint8_t motion = reg_read(PMW3610_REG_MOTION);
    if (motion & BIT(7)) {
        // raw value
        if (false) {
            Serial.write("Motion = ");
            Serial.println(motion);
            Serial.write("delta_x = ");
            Serial.println(reg_read(PMW3610_REG_DELTA_X_L));
            Serial.write("delta_y = ");
            Serial.println(reg_read(PMW3610_REG_DELTA_Y_L));
            Serial.write("delta_xy = ");
            Serial.println(reg_read(PMW3610_REG_DELTA_XY_H));
        }
        // parsed value
        if (true) {
            uint8_t xl  = reg_read(PMW3610_REG_DELTA_X_L);
            uint8_t yl  = reg_read(PMW3610_REG_DELTA_Y_L);
            uint8_t xyh = reg_read(PMW3610_REG_DELTA_XY_H);
            int16_t x   = TOINT16(xl + ((xyh & 0xF0) << 4), 12);
            int16_t y   = TOINT16(yl + ((xyh & 0x0F) << 8), 12);
            Serial.printf("x = %d y = %d\n", x, y);
        }
    } else {
        Serial.write(".");
    }
    delay(100);
}

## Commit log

2025-03-18 Add case data
    [bottom-left.stl, bottom-right.stl, led.stl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]
2025-03-22 Add booth link and schematic picture
